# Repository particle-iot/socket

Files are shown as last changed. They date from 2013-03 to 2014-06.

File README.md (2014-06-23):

The Spark Socket
=====

These are the design files for the Spark Socket, developed by Hex Labs, Inc. dba Spark Devices.

These files have been made available online through a [Creative Commons Attribution-ShareAlike 3.0](http://creativecommons.org/licenses/by-sa/3.0/) license.

You are welcome to distribute, remix, and use these files for commercial purposes. If you do so, please attribute the original design to Spark Devices both on the website and on the physical packaging of the product or in the instruction manual. All derivative works must be published under the same or a similar license.

## WARNING: High voltage

If you choose to use these design files, please be forewarned: working with high voltage designs, especially non-isolated ones, can be extremely dangerous. Please proceed with extreme caution. We cannot guarantee the safety of these designs, as they had not yet been put through certification. If you download these files, you are taking upon yourself any liability for injury or property damage.

## The Story

Development of the Spark Socket began in December, 2011, sparked (sorry) by Zach's experiences with his deaf father. Over the next eleven months, Spark went from an idea to a product. On November 13, 2012, the Spark Socket was published on the crowdfunding platform Kickstarter. The Kickstarter campaign site can be found [here](http://www.kickstarter.com/projects/sparkdevices/spark-upgrade-your-lights-with-wi-fi-and-apps).

The Spark Socket Kickstarter campaign ran from November 13, 2012 to December 13, 2012. In that time, roughly 1,600 individuals devoted their time and money to supporting Spark with a total of $125,588 pledged. The funding threshold, however, for the campaign was $250,000. Because that threshold was not reached by the end of the campaign, the campaign closed unsuccessfully, and no credit cards were charged.

The Spark team continued to work on the Spark Socket after the close of the campaign, taking pre-orders on [their website](http://www.sparkdevices.com) . Between December 13, 2012 and March 25, 2013, orders for ~1,800 Spark Sockets were placed; many were from previous Kickstarter backers, and many more were from newcomers.

On March 25, 2013, the Spark team announced that they would be discontinuing development work on the Spark Socket. The design files for the product were released here on github for others to use and learn from.

## What's Included

This distro contains two versions of the Spark Socket, named Version 1 and Version 2.

Version 1 of the Spark Socket is the version that was showcased in our Kickstarter video. The design includes four circuit boards, wrapped in a cuboid shape around the inner core of the plastic enclosure.

As development on the Socket continued, Version 2 of the Spark Socket was created. Version 2 re-oriented the design so that there are only two circuit boards: one with the high voltage components of the circuit, the other with the low voltage components of the circuit. This design made integrating the power supply much easier, and would be significantly easier to assemble. It also had enough empty space that the plastic enclosure could theoretically be made smaller, although development efforts stopped before the outer enclosure was changed.

## Basic structure

The design of the Spark Socket includes four major subsystems:

- **Power supply**. The Socket sources the power for its circuitry directly from the high-voltage AC line to which it is attached. Although this may be possible with an isolated switch-mode power supply, we chose a non-isolated design to save on the bill of materials and to save space. The power supply must be able to source at least 300mA of current (mostly for the transmit events of the Wi-Fi module), although the average power draw should be closer to 50mA.
- **Micro-controller**. Because the Spark Socket was originally built using an Arduino, the micro-controller we are using is an Atmel ATmega328p. This is a low-cost 8-bit micro-controller that is very easy to develop for. For encrypted communications, a 32-bit micro-controller (such as an STM32 Cortex M3) may be used instead.
- **Wi-Fi module**. For the Socket prototype, we used a Roving Networks RN-171 Wi-Fi module. These modules are great because they are very easy to work with and get up and running quickly. They are, however, quite expensive; even with high volumes, the order price was greater than $15. Spark will be using the Texas Instruments CC3000 Wi-Fi module in our other projects, which is smaller, lower cost, and has a simpler set-up process. We recommend the CC3000 for ongoing development work.
- **TRIAC Dimmer**. The most tried-and-true way to dim a light bulb is using a TRIAC. A zero-cross detector informs the micro-controller of the timing of the AC current, and the TRIAC dimmer is activated at a specificied time interval after the zero-cross, based on the chosen dim level. TRIAC dimmers work best with resistive loads (such as incandescent bulbs), and will also work with CFLs that are labeled "dimmable" as well as LED bulbs that are labeled "dimmable". TRIAC dimmers are also called "leading edge" dimmers.

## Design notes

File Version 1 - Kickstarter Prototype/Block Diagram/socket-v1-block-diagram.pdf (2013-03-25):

Potential design changes:
- Use a lower cost Wi-Fi module
- Use a transformerless power supply
- Add a current sensor

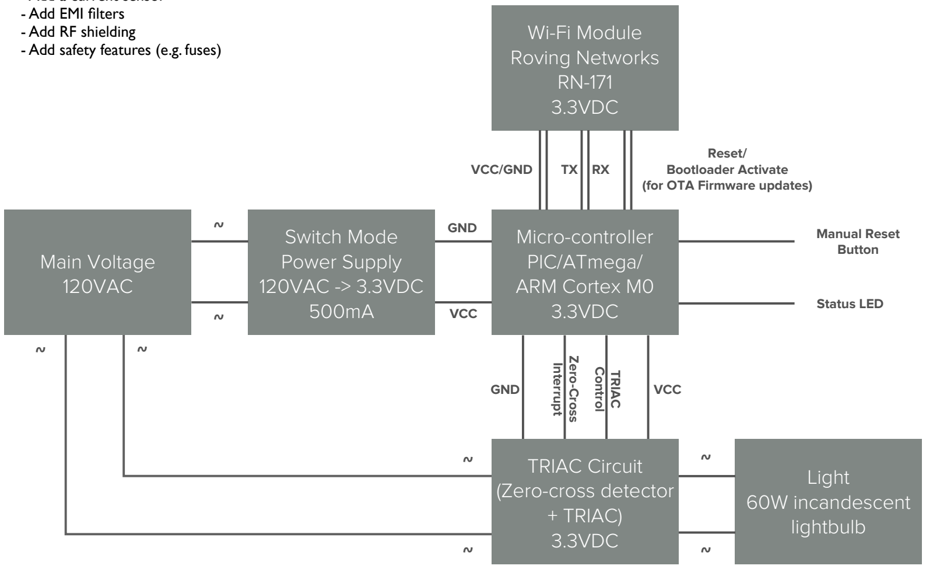
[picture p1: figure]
Switch Mode Power Supply 120VAC -> 3.3VDC 500mA; Micro-controller PIC/ATmega/ ARM Cortex M0 3.3VDC; Wi-Fi Module Roving Networks RN-171 3.3VDC; Light 60W incandescent lightbulb; VCC; GND; Reset/ Bootloader Activate (for OTA Firmware updates); Zero-Cross; Interrupt; Control; TRIAC; VCC/GND; Manual Reset Button; Status LED; Main Voltage 120VAC; TRIAC Circuit (Zero-cross detector + TRIAC) 3.3VDC; - Add EMI filters - Add RF shielding - Add safety features (e.g. fuses)

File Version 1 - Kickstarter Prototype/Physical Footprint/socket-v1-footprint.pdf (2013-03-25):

# Insert

54mm max outer diameter
49mm inner diameter

Shell

PCB

28mm inner diameter
32mm outer diameter
(2mm thick plastic)

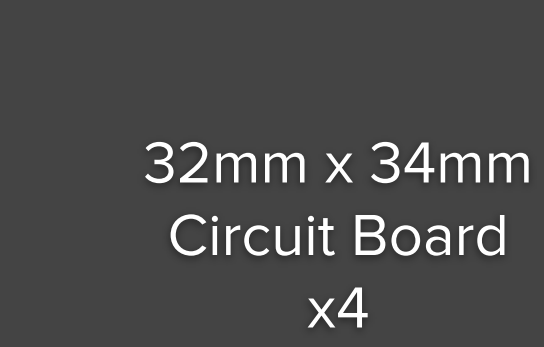
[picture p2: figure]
32mm x 36mm Circuit Board x4; 32mm x 34mm Circuit Board x4

Shell max height: 42mm
PCB height: 34mm
Insert top gradient: 4mm (Z-axis) Shell bottom gradient: 2mm (Z-axis) Plastic thickness: 2mm
34 + 4 + 2 + 2 = 42mm

Thursday, September 27, 12

Female socket
28mm x 22mm

Available space for power supply 28mm x 12mm

Available space for
power supply
19mm x 18mm

PCB

PCB

42mm | 34

23mm
outer diameter

28mm
inner diameter

19mm
inner diameter

49mm
inner diameter

16mm

Thursday, September 27, 12

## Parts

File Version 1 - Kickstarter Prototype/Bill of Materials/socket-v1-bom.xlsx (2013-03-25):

 | SwitchDevices RFQ BOM for <<CM>>
 | 2012-10-08
 | *** Company Confidential *** |  |  |  |  | Material | Density (g/cm3) | Density (lb/in3)
 | Bill@DragonInnovation.com |  |  |  |  | ABS | 1.04 | 0.037
 |  |  |  |  |  | PC | 1.20 | 0.043
CM Instructions: | 1. Please fill in all yellow cells. |  |  |  |  | Nylon | 1.15 | 0.041
 | 2. All costs in USD. |  |  |  |  | Santoprene | 0.97 | 0.035
 | 3. All units in English. |  |  |  |  | Silicone | 1.20 | 0.043
 | 4. Please add any additional costs |  |  |  |  | Styrene | 0.91 | 0.033
 |  |  |  |  |  | POM | 1.41 | 0.051
 |  |  |  |  |  | Aluminum | 2.70 | 0.097
 |  |  |  |  |  | Stainless Steel | 8.03 | 0.289
Molded Parts
Production Tool Cost | Part Name | P/N | Image | Approx Outer Dimensions (L x W X D) | Resin | Color | Resin Cost USD/ Kg | Individual Part Volume (mm3) | Individual Part Weight (g) | Cavities (Usage) | Up | Total Part Weight / Shot (g) | Sprue & Runner Weight (g) | Shot Weight (g) | Regrind % | Virgin Resin Weight / Shot (g) | Material Cost per piece | Press Tonnage | Cycle Time (s) | Press Tonnage Hourly Labor Rate | Mold Type | Molding Cost | Molding Cost / Piece | Production Cost per Piece | Cost per Assy | Total Weekly Capacity
$9738 | Shell | Enclosure2 |  | 55x55x40.5 | PC-ABS V0 Flame Retardant | varies | $4.00 | 18234.3 | 20.42 | 1 | 1 | 20.5763 | 2.05763 | 22.63395 | 0% | 22.63395 | $0.091 |  | 40 | $8.00 |  | $0.089 | $0.089 | $0.179 | $0.179
 | Pairing/Reset Button | Temp003 | No image - small button that is always the same color as the Housing and is molded in a family mold with the Shell | 5x5x7 |  |  |  | 137.4 | 0.15 | 1 | 1
$1640 | Light-pipe | Lightpipe1 | No image - small star-shaped light-pipe that conducts light from LED on PCB to exterior | 4x4x7 | Acrylic or PC V0 Flame Retardant | clear | $5.00 | 88.0 | 0.09 | 1 | 1 | 0.0915 | 0.00915 | 0.10063 | 0% | 0.10063 | $0.001 |  | 20 | $8.00 |  | $0.044 | $0.044 | $0.045 | $0.045
$8649 | Insert | Enclosure1 |  | 49.5x49.5x54 | PC-ABS V0 Flame Retardant | varies | $4.00 | 12218.2 | 13.68 | 1 | 1 | 13.6843 | 1.36843 | 15.05277 | 0% | 15.05277 | $0.060 |  | 40 | $8.00 |  | $0.089 | $0.089 | $0.149 | $0.149
$20027 | Injection Tooling |  |  |  |  |  |  |  |  |  |  |  |  |  |  |  |  |  |  |  |  |  |  | Total Mech | $0.373
Purchased Parts
Usage | Part Name | P/N | Image | Material | Unit Cost | Extended Cost
1 | Screw to attach male Edison screw | Screw3 |  | Stainless steel | $0.080 | $0.080
1 | Screw to attach female Edison screw | Screw4 |  | Stainless steel | $0.080 | $0.080
1 | Male E27 Edison Screw Assembly, see http://www.alibaba.com/product-gs/354788193/GOOD_Lamp_base_E27_Aluminum_Nickel.html | Edison1 |  | Aluminum nickel free solder | $0.080 | $0.080
1 | Female E27 Edison Screw Assembly, see http://www.alibaba.com/product-gs/354775792/GREAT_Lamp_base_E27_Brass_Shrapnel.html | Edison2 |  | Aluminum nickel free solder | $0.220 | $0.220
1 | Wire Hrness between MALE & POWPRI | WH1 |  | Each is a set of four insulated tinned jumper wires | $0.070 | $0.070
1 | Wire Hrness between MALE & DIMMER | WH2 |  | Each is a set of four insulated tinned jumper wires | $0.070 | $0.070
1 | Wire Hrness between FEMALE & DIMMER | WH3 |  | Each is a set of four insulated tinned jumper wires | $0.070 | $0.070
 |  |  |  |  |  | $0.000
 |  |  |  |  |  | $0.000
 |  |  |  |  | Total Purchased | $0.670
 |  |  |  |  |  |  |  |  |  |  |  |  |  |  |  |  |  |  |  | Threshold | $1.00
Item | Description | Usage | Reference | Current Manufacturer | Current Mfg P/N | Possible Alternates | Local Supplier Name | Local Supplier Part Number | Unit Cost | MOQ | Lead-Time (days) | Extended Cost | Unit Cost <= Threshold | Unit Cost > Threshold | Notes
1 | Chip Antenna, 2.4Ghz, SMD 2.2x6.5mm | 1 | A1 | Linx Technologies Inc | ANT-2.45-CHP-T |  |  |  | 0 | ~10K |  | $0.000 | $0.000 |  | Removed
2 | Bridge Rectifier, 400V, DF-S | 1 | B1 | Diodes inc | DF1504S |  |  |  | 0.162 | ~10K |  | $0.162 | $0.162
3 | Bridge rectifier, 0.5A, 600V, SOIC4 | 1 | B2 | Vishay General Semiconductor | MB6S-E3/80 |  |  |  | 0.109 | ~10K |  | $0.109 | $0.109
4 | Button, 5mm height, 6mm | 1 | BUTTON1 | Omron Electronics | B3F-1022 |  |  |  | 0.189 | ~10K |  | $0.189 | $0.189
5 | Capacitor, 1uF, 0603 | 1 | C1 | Std |  |  |  |  | 0.005 | ~10K |  | $0.005 | $0.005
6 | Electrolytic capacitor, 6.8uF, 400V, 8mmx16mm, 5mm leads | 1 | C10 | TEAPO | ?? |  |  |  | 0.141 | ~10K |  | $0.141 | $0.141
7 | Electrolytic capacitor, 470uF, 6.3V, 6.3mmx11mm, 5mm leads | 1 | C11 | Rubycon | 6.3ZLH470M6 |  |  |  | 0.072 | ~10K |  | $0.072 | $0.072
8 | Electrolytic capacitor, 470uF, 6.3V, 6.3mmx11mm, 5mm leads | 1 | C12 | Rubycon | 6.3ZLH470M6 |  |  |  | 0.072 | ~10K |  | $0.072 | $0.072
9 | Ceramic capacitor, 0.1uF, 0603 | 1 | C13 | Std | Std |  |  |  | 0.0045 | ~10K |  | $0.004 | $0.004
10 | Electrolytic capacitor, 10uF, 1206 | 1 | C2 | Std |  |  |  |  | 0.02 | ~10K |  | $0.020 | $0.020
11 | Ceramic capacitor, 0.1uF, 450V, 1206 | 1 | C3 | TDK | C3216X7T2W104M |  |  |  | 0.105 | ~10K |  | $0.105 | $0.105
12 | Capacitor, 0.1uF, 0603 | 1 | C4 | Std |  |  |  |  | 0.0045 | ~10K |  | $0.004 | $0.004
13 | Capacitor, 22pF, 0603 | 1 | C5 | Std |  |  |  |  | 0.09 | ~10K |  | $0.090 | $0.090
14 | Ceramic capacitor, 470pF, 630V, 1206 | 1 | C6 | Kemet | C1206C471KBRACTU |  |  |  | 0.19112 | ~10K |  | $0.191 | $0.191
15 | Ceramic capacitor, 8pF, 10V, 0603 | 1 | C7 | Std | Std |  |  |  | 0.0045 | ~10K |  | $0.004 | $0.004
16 | Ceramic capacitor, 0.33uF, 50V, 0603 | 1 | C8 | Std | Std |  |  |  | 0.0045 | ~10K |  | $0.004 | $0.004
17 | Capacitor, 22pF, 0603 | 1 | C9 | Std |  |  |  |  | 0.0045 | ~10K |  | $0.004 | $0.004
18 | Schotty Diode, 3A, 40V, SMA | 1 | D1 | ON | MBRA340T3G |  |  |  | 0.161 | ~10K |  | $0.161 | $0.161
19 | Switching diode, 0.2A, 200V, SOD323 | 1 | D2 | ON | BAS20HT1G |  |  |  | 0.028 | ~10K |  | $0.028 | $0.028
20 | Ultrafast rectifier, 1A, 600V, SMA | 1 | D3 | ON | MURA160T3G |  |  |  | 0.10687 | ~10K |  | $0.107 | $0.107
21 | Fuse, 300V, TE5 | 1 | F1 | Littelfuse Inc | 36911000000 |  |  |  | 0.18 | ~10K |  | $0.180 | $0.180
22 | PTC, 1A, 1206 | 1 | F2 | Littelfuse Inc | 1206L050YR |  |  |  | 0.178 | ~10K |  | $0.178 | $0.178
23 | Header b/w MCU & WIFI, 6 pin, right angle, 0.1 inch spacing | 1 | HEADER1 | TE Connectivity | 640385-6 |  |  |  | 0.33 | ~10K |  | $0.330 | $0.330
24 | Header b/w MCU & DIMMER, 4 pin, right angle, 0.1 inch spacing | 1 | HEADER2 | TE Connectivity | 640385-4 |  |  |  | 0.11 | ~10K |  | $0.110 | $0.110
25 | Header b/w WIFI & POWREG, 3 pin, right angle, 0.1 inch spacing | 1 | HEADER3 | Wurth | 640385-3 |  |  |  | 0.2 | ~10K |  | $0.200 | $0.200
26 | ICSP Headers, 2x3 (6 pins), 0.1 inch spacing | 3 | ICSP2 | Std |  |  |  |  | 0.11 | ~10K |  | $0.330 | $0.330
27 | Radial leaded wire transformer, 2.2mH, 5mmx8mm leaded | 1 | L1 | Wurth Electronik | 7447462222 |  |  |  | 0.175 | ~10K |  | $0.175 | $0.175
28 | LED, Green, 0603 | 1 | LED3 | Std |  |  |  |  | 0.07 | ~10K |  | $0.070 | $0.070
29 | LED, Yellow, 0603 | 1 | LED4 | Std |  |  |  |  | 0.07 | ~10K |  | $0.070 | $0.070
30 | LED, Red, 0603 | 1 | LED5 | Std |  |  |  |  | 0.07 | ~10K |  | $0.070 | $0.070
31 | LED, Red, 0603 | 1 | LED6 | Std |  |  |  |  | 0.07 | ~10K |  | $0.070 | $0.070
32 | Triple Output LED RGB; common anode, , 4-PLCC | 1 | LED7 | Cree Inc | CLVBA-FKA-CAEDH8BBB7A363 |  |  |  | 0.126 | ~10K |  | $0.126 | $0.126 |  | Replaced with http://www.digikey.com/product-detail/en/LTST-C19FD1WT/LTST-C19FD1WT-ND/3198709
33 | Printed Circuit Board, 26mmx28mm, Std, | 1 | PCB1 | Std |  |  |  |  | 0.080 | ~10K |  | $0.080 | $0.080
34 | Printed Circuit Board, 35mmx28mm, Std, | 1 | PCB2 | Std |  |  |  |  | 0.110 | ~10K |  | $0.110 | $0.110
35 | Printed Circuit Board, 35mmx28mm, | 1 | PCB3 | Std |  |  |  |  | 0.110 | ~10K |  | $0.110 | $0.110
36 | Printed Circuit Board, 26mmx28mm, Std, | 1 | PCB4 | Std |  |  |  |  | 0.080 | ~10K |  | $0.080 | $0.080
37 | Printed Circuit Board inside male shell 19 mm Diam. | 1 | PCB5 | Std |  |  |  |  | 0.050 | ~10K |  | $0.050 | $0.050
38 | Printed Circuit Board inside male shell 28 mm Diam. | 1 | PCB6 | Std |  |  |  |  | 0.100 | ~10K |  | $0.100 | $0.100
39 | Crystal, 12Mhz, HC49/US SMD | 1 | Q1 | ECS Inc | ECS-120-20-3X-TR |  |  |  | 0.189 | ~10K |  | $0.189 | $0.189
40 | NMOSFET, 2A, 600V, TO-220 | 1 | Q2 | Fairchild Semiconductor | FQP2N60C |  |  |  | 0.3 | ~10K |  | $0.300 | $0.300
41 | Resistor, 10K, 0603 | 1 | R1 | Std |  |  |  |  | 0.002 | ~10K |  | $0.002 | $0.002
42 | Resistor, 200 ohm, 0603 | 1 | R10 | Std |  |  |  |  | 0.002 | ~10K |  | $0.002 | $0.002
43 | Resistor, 200 ohm, 0603 | 1 | R11 | Std |  |  |  |  | 0.002 | ~10K |  | $0.002 | $0.002
44 | Resistor, 220 ohm, 0603 | 1 | R12 | Std |  |  |  |  | 0.002 | ~10K |  | $0.002 | $0.002
45 | Resistor, 220 ohm, 0603 | 1 | R13 | Std |  |  |  |  | 0.002 | ~10K |  | $0.002 | $0.002
46 | Resistor, 220 ohm, 0603 | 1 | R14 | Std |  |  |  |  | 0.002 | ~10K |  | $0.002 | $0.002
47 | Resistor, 10K, 0603 | 1 | R15 | Std |  |  |  |  | 0.002 | ~10K |  | $0.002 | $0.002
48 | Resistor, 4.7K, 0805 | 1 | R16 | Std | Std |  |  |  | 0.002 | ~10K |  | $0.002 | $0.002
49 | Resistor, 10K, 0603 | 1 | R17 | Std |  |  |  |  | 0.002 | ~10K |  | $0.002 | $0.002
50 | Resistor, 330K, 1206 | 1 | R18 | Std | Std |  |  |  | 0.002 | ~10K |  | $0.002 | $0.002
51 | Resistor, 0ohm, 1206 | 1 | R19 | Std | Std |  |  |  | 0.002 | ~10K |  | $0.002 | $0.002
52 | Resistor, 47K, 0603 | 1 | R2 | Std |  |  |  |  | 0.002 | ~10K |  | $0.002 | $0.002
53 | Resistor, 7.5M, 1206 | 1 | R20 | Std | Std |  |  |  | 0.002 | ~10K |  | $0.002 | $0.002
54 | Resistor, 7.5M, 1206 | 1 | R21 | Std | Std |  |  |  | 0.002 | ~10K |  | $0.002 | $0.002
55 | Resistor, 33R, 0603 | 1 | R22 | Std | Std |  |  |  | 0.002 | ~10K |  | $0.002 | $0.002
56 | Resistor, 150K, 0603 | 1 | R23 | Std | Std |  |  |  | 0.002 | ~10K |  | $0.002 | $0.002
57 | Resistor, 28K, 0603 | 1 | R24 | Std | Std |  |  |  | 0.002 | ~10K |  | $0.002 | $0.002
58 | Resistor, 47K, 0603 | 1 | R26 | Std | Std |  |  |  | 0.002 | ~10K |  | $0.002 | $0.002
59 | Resistor, 2.4K, 0603 | 1 | R27 | Std | Std |  |  |  | 0.002 | ~10K |  | $0.002 | $0.002
60 | Resistor, 2.4ohm, 0603 | 1 | R28 | Std | Std |  |  |  | 0.002 | ~10K |  | $0.002 | $0.002
61 | Resistor, 18ohm, 0805 | 1 | R29 | Std | Std |  |  |  | 0.002 | ~10K |  | $0.002 | $0.002
62 | Resistor, 47K, 0603 | 1 | R3 | Std |  |  |  |  | 0.002 | ~10K |  | $0.002 | $0.002
63 | Resistor, 4.7K, 0603 | 1 | R30 | Std | Std |  |  |  | 0.002 | ~10K |  | $0.002 | $0.002
64 | Resistor, 330ohm, 0603 | 1 | R4 | Std |  |  |  |  | 0.002 | ~10K |  | $0.002 | $0.002
65 | Resistor, 470ohm, 0603 | 1 | R5 | Std |  |  |  |  | 0.002 | ~10K |  | $0.002 | $0.002
66 | Resistor, 1K, 0603 | 1 | R6 | Std |  |  |  |  | 0.002 | ~10K |  | $0.002 | $0.002
67 | Resistor, 1K, 0603 | 1 | R7 | Std |  |  |  |  | 0.002 | ~10K |  | $0.002 | $0.002
68 | Resistor, 1M, 0603 | 1 | R8 | Std |  |  |  |  | 0.002 | ~10K |  | $0.002 | $0.002
69 | Resistor, 100 ohm, 0603 | 1 | R9 | Std |  |  |  |  | 0.002 | ~10K |  | $0.002 | $0.002
70 | Screw to attach MCU to INSERT, , | 1 | SCREW1 | Std |  |  |  |  | 0.03 | ~10K |  | $0.030 | $0.030
71 | Screw to attach POWREG to INSERT, , Std | 1 | SCREW2 | Std |  |  |  |  | 0.03 | ~10K |  | $0.030 | $0.030
72 | Screw to attach POWREG to INSERT, , | 1 | SCREW3 | Std |  |  |  |  | 0.03 | ~10K |  | $0.030 | $0.030
73 | TRIAC, 600V, SOT-223 | 1 | T1 | NXP Semiconductors | ACT108W-600E,135 |  |  |  | 0.17 | ~10K |  | $0.170 | $0.170
74 | Transformer, EPC13, Custom | 1 | TR1 | Wurth Electronik | 750341445 |  |  |  | 0 | ~10K |  | $0.000 | $0.000 |  | Removed
75 | Optoisolator transistor, , 6-SMD | 1 | U1 | Fairchild Optoelectronics Group | 4N25SR2M |  |  |  | 0.163 | ~10K |  | $0.163 | $0.163
76 | Optoisolator TRIAC driver, 400V, 6-SMD | 1 | U2 | Lite-On Inc | MOC3021S |  |  |  | 0.21735 | ~10K |  | $0.217 | $0.217
77 | 3.3V voltage regulator, 3.3V, SOT-235 | 1 | U3 | Micrel Inc | MIC5219-3.3YM5 TR |  |  |  | 0 | ~10K |  | $0.000 | $0.000 |  | Removed
78 | ATmega328p Micro-controller, ATmega328p, 32TQFP | 1 | U4 | Atmega | ATMEGA328P-AU |  |  |  | 1.76 | ~10K |  | $1.760 |  | $1.760
79 | Roving Networks RN-171 Wi-Fi Module, 802.11b/g, Custom SMD | 1 | U5 | Roving Networks | 740-1042-ND |  |  |  | 12.5 | ~10K |  | $12.500 |  | $12.500 | Replaced with GainSpan 1011MIPS
80 | PSR Controller, UCC28700, TSOP-6 | 1 | U6 | Texas Instruments | UCC28700 |  |  |  | 0.49 | ~10K |  | $0.490 | $0.490
 |  |  |  |  |  |  |  |  |  |  | Total | $19.851 | $5.591 | $14.260
Production Labor Cost Per Unit | $5.50
Shipment Packaging
Usage | Description | Unit Cost | Setup / Tooling Cost | Extended Cost
0.0833 | Master Carton | $0.350 |  | $0.029
1 | Gift Box, 4x4" | $0.850 |  | $0.850 | Replace with printed corrugated shipper; no price difference
1 | Foam packaging (FOAM) | $0.250 | $80 | $0.250 | Reduced to $0.25 (cheaper packaging)
1 | Slip Cover, 4-Color | $0.000 |  | $0.000 | Removed
1 | Warranty Card | $0.050 |  | $0.050
1 | Instructions, 1 page on B&W stock | $0.250 |  | $0.250
2 | Tape | $0.020 |  | $0.040
 |  |  | Shipment Packaging Total | $1.469
 |  |  | Giftbox Packaging (Injection) | $0.000
 |  |  | Total Packaging | $1.469
 |  |  | Packout Labor Cost / Unit | $0.400
 | COGS Summary | Value
 | Special Component Threshold | $1.00
 | Labor Rate per Hour
 | Standard Factory Profit (%) | 15.00%
 | Special Materials Factory Profit (%) | 8.00%
 | Consigned Goods Markup (%)
 | Total Mechanical Costs (including Packaging) | $2.51
 | Total Standard Electrical Costs | $5.59
 | Total Special Electrical Costs | $14.26
 | Total Consigned Costs | $0.00
 | Total Material Costs | $22.36
 | Total Labor Cost (including Packaging) | $5.90
 | Total Markup | $3.24
 | Total XF Cost | $31.50
 | Overland Transportation - 20ft | Value
 | HK FCL
 | HK LCL
 | YanTian FCL
 | YanTian LCL
 | Total Costs | Value
 | FOB, HK FCL | $31.50
 | FOB, HK LCL | $31.50
 | FOB, YanTian FCL | $31.50
 | FOB, YanTian LCL | $31.50
 | Total Tooling Costs | $20107

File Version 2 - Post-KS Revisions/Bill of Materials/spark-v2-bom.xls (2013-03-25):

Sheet: Components
System | Part | Description | Value | Package | Manufacturer | Mgfr Part # | DigiKey Part # | Link | Cost @ 1 unit | Cost @ 10K units | Notes | Quantity
MCU | U4 | ATmega328p Micro-controller | ATmega328p | 32TQFP | Atmega | ATMEGA328P-AU | ATMEGA328P-AU-ND | http://www.digikey.com/product-detail/en/ATMEGA328P-AU/ATMEGA328P-AU-ND/1832260 | $3.0500 | $1.7600 | Will probably switch to QFN for production design | 1
MCU | R8 | Resistor | 1M | 0603 | Panasonic Electronics Components | ERJ-3GEYJ105V | P1.0MGCT-ND | http://www.digikey.com/product-detail/en/ERJ-3GEYJ105V/P1.0MGCT-ND/134885 |  |  |  | 1
MCU | R15 | Resistor | 10K | 0603 | Panasonic Electronics Components | ERJ-3GEYJ103V | P10KGCT-ND | http://www.digikey.com/product-detail/en/ERJ-3GEYJ103V/P10KGCT-ND/134717 |  |  |  | 1
MCU | Q1 | Crystal | 8Mhz | HC49/US SMD | ECS Inc | ECS-80-18-5PX-TR | XC1271CT-ND | http://www.digikey.com/product-detail/en/ECS-80-18-5PX-TR/XC1271CT-ND/827735 | $0.5300 | $0.1890 | Bump to 12Mhz? | 1
MCU | C5 | Capacitor | 22pF | 0603 | TDK Corporation | C1608C0G1H220J | 445-1273-1-ND | http://www.digikey.com/product-detail/en/C1608C0G1H220J/445-1273-1-ND/567670 |  |  | Must match the crystal | 1
MCU | C9 | Capacitor | 22pF | 0603 | TDK Corporation | C1608C0G1H220J | 445-1273-1-ND | http://www.digikey.com/product-detail/en/C1608C0G1H220J/445-1273-1-ND/567670 |  |  | Must match the crystal | 1
MCU | LED7 | Triple Output LED RGB; common anode |  | 4-PLCC | Cree Inc | CLVBA-FKA-CAEDH8BBB7A363 | CLVBA-FKA-CAEDH8BBB7A363CT-ND | http://www.digikey.com/product-detail/en/CLVBA-FKA-CAEDH8BBB7A363/CLVBA-FKA-CAEDH8BBB7A363CT-ND/2650500 | $0.5500 | $0.2730 |  | 1
MCU | R9 | Resistor | 100 ohm | 0603 | Panasonic Electronics Components | ERJ-3GEYJ101V | P100GCT-ND | http://www.digikey.com/product-detail/en/ERJ-3GEYJ101V/P100GCT-ND/134714 |  |  |  | 1
MCU | R10 | Resistor | 200 ohm | 0603 | Panasonic Electronics Components | ERJ-3GEYJ201V | P200GCT-ND | http://www.digikey.com/product-detail/en/ERJ-3GEYJ201V/P200GCT-ND/134748 |  |  |  | 1
MCU | R11 | Resistor | 200 ohm | 0603 | Panasonic Electronics Components | ERJ-3GEYJ201V | P200GCT-ND | http://www.digikey.com/product-detail/en/ERJ-3GEYJ201V/P200GCT-ND/134748 |  |  |  | 1
WIFI | U5 | Roving Networks RN-171 Wi-Fi Module | 802.11b/g | Custom SMD | Roving Networks | 740-1042-ND | 740-1042-ND | http://www.digikey.com/product-search/en/rf-if-and-rfid/rf-transceivers/3539948?k=rn-171 | $33.3300 | $15.0000 | 10K price quoted from Roving Networks. We expect to replace this with a lower cost module. Alternatives can be found on the "Potential Wi-Fi Modules" worksheet | 1
WIFI | LED3 | LED | Green | 0603 | Vishay Semiconductors | LTST-C190KGKT | 160-1435-1-ND | http://www.digikey.com/product-detail/en/LTST-C190KGKT/160-1435-1-ND/386814 |  |  |  | 1
WIFI | LED4 | LED | Yellow | 0603 | Vishay Semiconductors | LTST-C190KFKT | 160-1434-1-ND | http://www.digikey.com/product-detail/en/LTST-C190KFKT/160-1434-1-ND/386812 |  |  |  | 1
WIFI | LED5 | LED | Red | 0603 | Lite-On Inc | LTST-C190KRKT | 160-1436-1-ND | http://www.digikey.com/product-detail/en/LTST-C190KRKT/160-1436-1-ND/386816 |  |  |  | 1
WIFI | R12 | Resistor | 220 ohm | 0603 | Std | ERJ-3GEYJ221V | P220GCT-ND | http://www.digikey.com/product-detail/en/ERJ-3GEYJ221V/P220GCT-ND/134754 |  |  |  | 1
WIFI | R13 | Resistor | 220 ohm | 0603 | Std | ERJ-3GEYJ221V | P220GCT-ND | http://www.digikey.com/product-detail/en/ERJ-3GEYJ221V/P220GCT-ND/134754 |  |  |  | 1
WIFI | R14 | Resistor | 220 ohm | 0603 | Std | ERJ-3GEYJ221V | P220GCT-ND | http://www.digikey.com/product-detail/en/ERJ-3GEYJ221V/P220GCT-ND/134754 |  |  |  | 1
WIFI | A1 | Chip Antenna | 2.4Ghz | SMD 2.2x6.5mm | Linx Technologies Inc | ANT-2.45-CHP-T | ANT-2.45-CHPCT-ND | http://www.digikey.com/product-detail/en/ANT-2.45-CHP-T/ANT-2.45-CHPCT-ND/523153 | $1.4200 | $1.1250 | Expect to replace with etched antenna or find a WiFi module with integrated antenna | 1
DIMMER | U1 | Optoisolator transistor |  | 6-SMD | Fairchild Optoelectronics Group | 4N25SR2M | 4N25SR2MCT-ND | http://www.digikey.com/product-detail/en/4N25SR2M/4N25SR2MCT-ND/2094169 | $0.6800 | $0.1630 |  | 1
DIMMER | U2 | Optoisolator TRIAC driver | 400V | 6-SMD | Lite-On Inc | MOC3021S | 160-1375-5-ND | http://www.digikey.com/product-detail/en/MOC3021S/160-1375-5-ND/385845 | $0.6500 | $0.2173 |  | 1
DIMMER | B1 | Bridge Rectifier | 400V | DF-S | Diodes inc | DF1504S | DF1504SDICT-ND | http://www.digikey.com/product-detail/en/DF1504S-T/DF1504SDICT-ND/350404 | $0.5900 | $0.1620 |  | 1
DIMMER | R1 | Resistor | 10K | 0603 | Panasonic Electronics Components | ERJ-3GEYJ103V | P10KGCT-ND | http://www.digikey.com/product-detail/en/ERJ-3GEYJ103V/P10KGCT-ND/134717 |  |  |  | 1
DIMMER | R2 | Resistor | 47K | 1206 | Vishay Dale | CRCW120647K0JNEAHP | 541-47KUACT-ND | http://www.digikey.com/product-detail/en/CRCW120647K0JNEAHP/541-47KUACT-ND/2222999 |  |  |  | 1
DIMMER | R3 | Resistor | 47K | 1206 | Vishay Dale | CRCW120647K0JNEAHP | 541-47KUACT-ND | http://www.digikey.com/product-detail/en/CRCW120647K0JNEAHP/541-47KUACT-ND/2222999 |  |  |  | 1
DIMMER | R4 | Resistor | 330ohm | 0603 | Panasonic Electronics Components | ERJ-3GEYJ331V | P330GCT-ND | http://www.digikey.com/product-detail/en/ERJ-3GEYJ331V/P330GCT-ND/134778 |  |  |  | 1
DIMMER | R5 | Resistor | 470ohm | 0603 | Panasonic Electronics Components | ERJ-3GEYJ471V | P470GCT-ND | http://www.digikey.com/product-detail/en/ERJ-3GEYJ471V/P470GCT-ND/134802 |  |  |  | 1
DIMMER | R6 | Resistor | 1K | 1206 | Vishay Dale | CRCW12061K00JNEAHP | 541-1.0KUACT-ND | http://www.digikey.com/product-detail/en/CRCW12061K00JNEAHP/541-1.0KUACT-ND/2222989 |  |  |  | 1
DIMMER | T1 | TRIAC | 600V | SOT-223 | NXP Semiconductors | ACT108W-600E,135 | 568-4912-1-ND | http://www.digikey.com/product-detail/en/ACT108W-600E,135/568-4912-1-ND/2122742 | $0.6200 | $0.1700 | Will need a heftier TRIAC for production | 1
DIMMER | LED1 | LED | Green | 0603 | Vishay Semiconductors | LTST-C190KGKT | 160-1435-1-ND | http://www.digikey.com/product-detail/en/LTST-C190KGKT/160-1435-1-ND/386814 |  |  |  | 1
POWREG | C13 | Capacitor | 0.1uF | 0603 | TDK Corporation | C1608X7R1E104K | 445-1316-1-ND | http://www.digikey.com/product-detail/en/C1608X7R1E104K/445-1316-1-ND/567697 |  |  |  | 1
POWREG | D1 | Schotty Diode | 3A, 40V | SMA | ON | MBRA340T3G | MBRA340T3GOSCT-ND | http://www.digikey.com/product-detail/en/MBRA340T3G/MBRA340T3GOSCT-ND/917975 | $0.5800 | $0.1610 |  | 1
POWREG | R30 | Resistor | 4.7K | 0603 | Panasonic Electronics Components | ERJ-3GEYJ472V | P4.7KGCT-ND | http://www.digikey.com/product-detail/en/ERJ-3GEYJ472V/P4.7KGCT-ND/135199 |  |  |  | 1
POWREG | C11 | Capacitor | 47uF | 1206 | TDK Corporation | C3216X6S0J476M | 445-6011-1-ND | http://www.digikey.com/product-detail/en/C3216X6S0J476M/445-6011-1-ND/2444052 |  |  |  | 1
POWREG | C12 | Capacitor | 47uF | 1206 | TDK Corporation | C3216X6S0J476M | 445-6011-1-ND | http://www.digikey.com/product-detail/en/C3216X6S0J476M/445-6011-1-ND/2444052 |  |  |  | 1
POWREG | F2 | PTC | 1A | 1206 | Littelfuse Inc | 1206L050YR | F2112CT-ND | http://www.digikey.com/product-detail/en/1206L050YR/F2112CT-ND/455721 | $0.4800 | $0.1780 |  | 1
POWREG | U3 | 3.3V voltage regulator | 3.3V | SOT-235 | Micrel Inc | MIC5219-3.3YM5 TR | 576-1281-1-ND | http://www.digikey.com/product-detail/en/MIC5219-3.3YM5%20TR/576-1281-1-ND/771902 | $1.4300 | $0.6980 |  | 1
POWREG | C2 | Capacitor | 10uF | 1206 | TDK Corporation | C3216X7R1H104M | 445-4008-1-ND | http://www.digikey.com/product-detail/en/C3216X7R1H104M/445-4008-1-ND/1965654 |  |  |  | 1
POWREG | C1 | Capacitor | 1uF | 0603 | TDK Corporation | C1608X7R1E105K | 445-5956-1-ND | http://www.digikey.com/product-detail/en/C1608X7R1E105K/445-5956-1-ND/2443997 |  |  |  | 1
POWREG | C4 | Capacitor | 0.1uF | 0603 | TDK Corporation | C1608X7R1E104K | 445-1316-1-ND | http://www.digikey.com/product-detail/en/C1608X7R1E104K/445-1316-1-ND/567697 |  |  |  | 1
POWREG | R7 | Resistor | 1K | 0603 | Panasonic Electronics Components | ERJ-3GEYJ102V | P1.0KGCT-ND | http://www.digikey.com/product-detail/en/ERJ-3GEYJ102V/P1.0KGCT-ND/134874 |  |  |  | 1
POWREG | LED6 | LED | Red | 0603 | Lite-On Inc | LTST-C190KRKT | 160-1436-1-ND | http://www.digikey.com/product-detail/en/LTST-C190KRKT/160-1436-1-ND/386816 |  |  |  | 1
POWREG | R17 | Resistor | 10K | 0603 | Panasonic Electronics Components | ERJ-3GEYJ103V | P10KGCT-ND | http://www.digikey.com/product-detail/en/ERJ-3GEYJ103V/P10KGCT-ND/134717 |  |  |  | 1
POWREG | BUTTON1 | Button | 5mm height | 6mm | Omron Electronics | B3F-1022 | SW403-ND | http://www.digikey.com/product-detail/en/B3F-1022/SW403-ND/44674 | $0.3500 | $0.1890 | May want to switch to surface mount | 1

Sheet: Specs
Attached bulb
 | Works with any dimmable light (incandescent, CFL, LED)
 | Up to 100W bulb when pointed upward
 | Up to 60W bulb when pointed downward (e.g. recessed lighting)
Quality
 | No visible parting lines
 | No visible blemishes
 | No visible solder or weld marks on either Edison screw
Power
 | Functions in any common AC voltage (85V to 265V)
 | Functions in either 60Hz or 50Hz
Resin
 | High melting point (to manage the heat from the bulb)
 | High light stability in indoor light (to prevent discoloration from the attached bulb)
 | V0 or V1 flame retardancy
 | Must pass glow-wire test and ball pressure test (for CE regulations)
Environmental
 | Product is intended only for indoor use; however, we would still like to reduce safety hazards related to outdoor use
RFI and EMI
 | Device must meet standard RFI and EMI requirements
 | Device must have a Wi-Fi range of 100-300 feet in a standard home; additional RF shielding may be necessary to limit noise from the TRIAC and power supply to achieve this performance
Compliance
 | FCC compliant
 | UL complaint with CCN OLRX (Standard - UL 406 Lamp Holders), CCN XACN3 (Standard - UL 60730-1 Automatic Electrical Controls for Household and Similar Use), and UL 1470: Solid State Dimming Controls.
 | Must meet any other safety and certification requirements to be sold in the US and Europe
Wi-Fi
 | Must be able to connect to a secured (WPA, WPA2, WEP) Wi-Fi 802.11 network
 | Must achieve at least 802.11b performance; may also achieve 802.11g and 802.11n
 | Must be able to create an ad hoc network
 | Must be able to communicate over standard TCP (IPv4 and IPv6)

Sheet: Potential Wi-Fi modules
Manufacturer | Model | Link | Price @ 1 unit | Price @ 10K | Price @ volume | Notes
Roving Networks | RN-171 | http://www.rovingnetworks.com/products/RN_171_RN171_I_RM | $33.00
Murata | SN8200 | http://www.murata-ws.com/sn8200.htm
GainSpan | GS1011MIPS | http://www.gainspan.com/gs1011mips | $33.00 | $12.50 | $10.50 | $12.5 at 10K, $10.5 at 25K
Inventek | ISM4319-M3-L44-E | http://www.inventeksys.com/products-page/wifi-modules/serial-wifi/ism4319-embedded-serial-to-wifi-module/
Inventek | ISM43362-M3G-L44-U (http://components.arrow.com/part/detail/53785148S181507N2846) | http://components.arrow.com/part/detail/53785148S181507N2846
??? | RAK410 | Found by Fred Zhang |  | $10 | $8
Bluegiga | WF121 | http://www.bluegiga.com/wf121-wi-fi-module
Redpine Signals | RS9110-N-11-22-(xx) | http://www.redpinesignals.com/Products/Modules/Connect-io-n/Wireless_Device_Server/RS9110-N-11-22.html
LS Research | TiWi-SL | http://www.lsr.com/wireless-products/tiwi-sl
Laird Technologies | WLM100 | http://www.mouser.com/ProductDetail/Laird-Technologies/WLM100/
WizNet | WizFi210 | http://www.wiznettechnology.com/Sub_Modules/en/product/Product_Detail.asp?cate1=&cate2=&cate3=&pid=1132

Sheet: Assembly steps
1) Mold the two plastic components
2) Laser-etch unique ID number and necessary labels (e.g. UL certification, voltage allowances, etc.) on the bottom of the shell
3) Solder components to 5 PCBs.
4) Load software onto MCU using the 6-pin ICSP headers
5) Weld wires/wire harnesses to the inside of the male Edison screw and the bottom of the female Edison screw
6) Bolt the male Edison screw to the bottom of the Insert
7) Solder the first set of wires from the male Edison screw to the primary-side power supply
8) Snap the primary-side power supply PCB into the inside of the insert
9) Attach 4 PCBs in square shape using soldered 90-degree headers
10) Screw 4 PCB square structure to Insert
11) Bolt the female Edison screw to the inside of the Insert
12) Solder the second set of wires from the male Edison screw to the dimmer circuit
13) Solder the wires from the female Edison screw to the dimmer circuit
14) Electrically connect 4 PCBs to primary-side power supply with wire harnesses
15) Test circuit
16) Snap Light pipe into Shell
17)Snap Shell/Light Pipe assembly onto PCB/Insert assembly
18)Test status light and reset button to ensure proper alignment
19)Visual inspection
20)Packaging

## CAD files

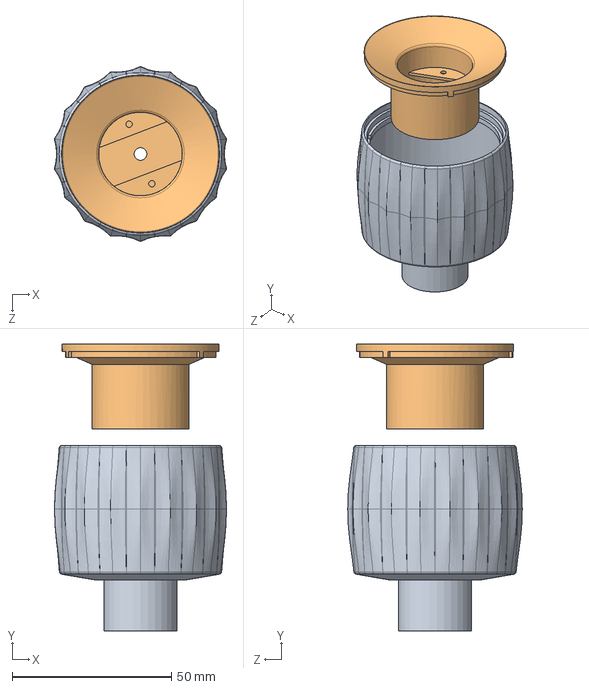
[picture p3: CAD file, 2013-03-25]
Version 2 - Post-KS Revisions/Plastic Shell/socket-v2-assembly.SLDASM
54.0 x 90.2 x 54.9 mm
Pinch_091812-Outer
Pinch_091812-Inner

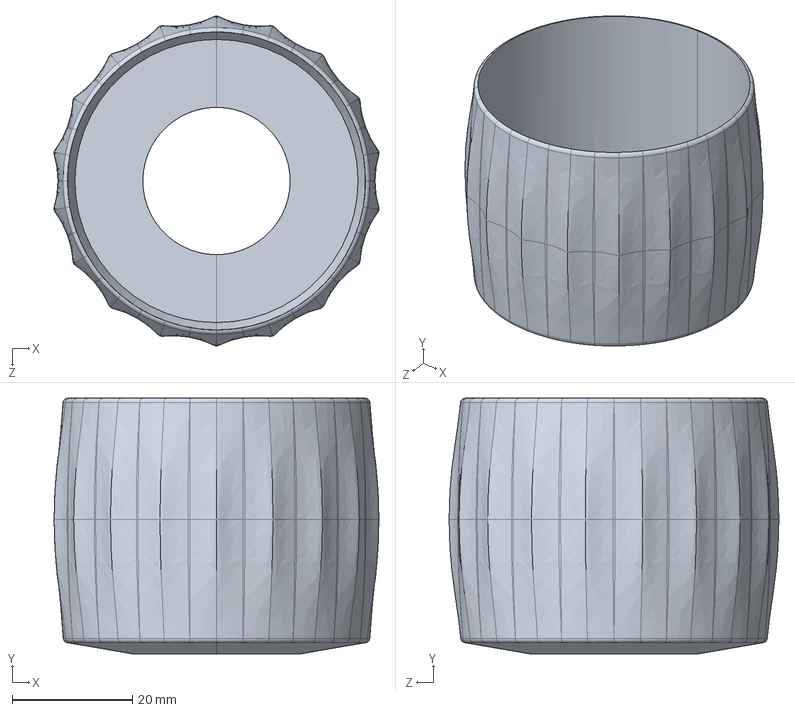
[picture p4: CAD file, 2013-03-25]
Version 1 - Kickstarter Prototype/Plastic Shell/socket-v1-outer-shell.STEP
54.0 x 42.5 x 54.9 mm

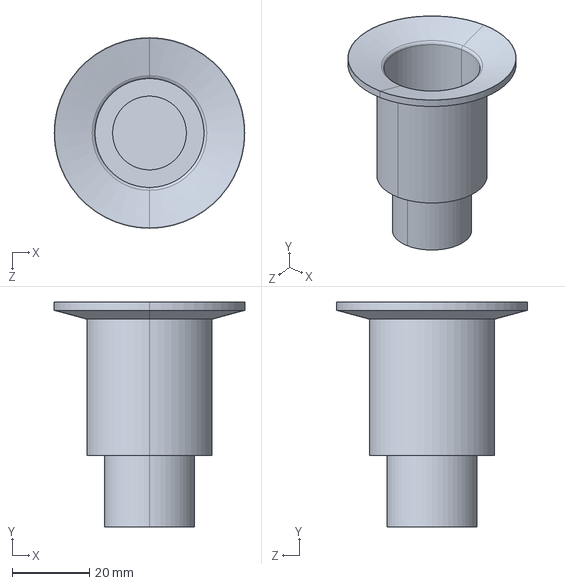
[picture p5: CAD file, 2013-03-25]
Version 1 - Kickstarter Prototype/Plastic Shell/socket-v1-inner-shell.STEP
49.3 x 58.3 x 49.3 mm

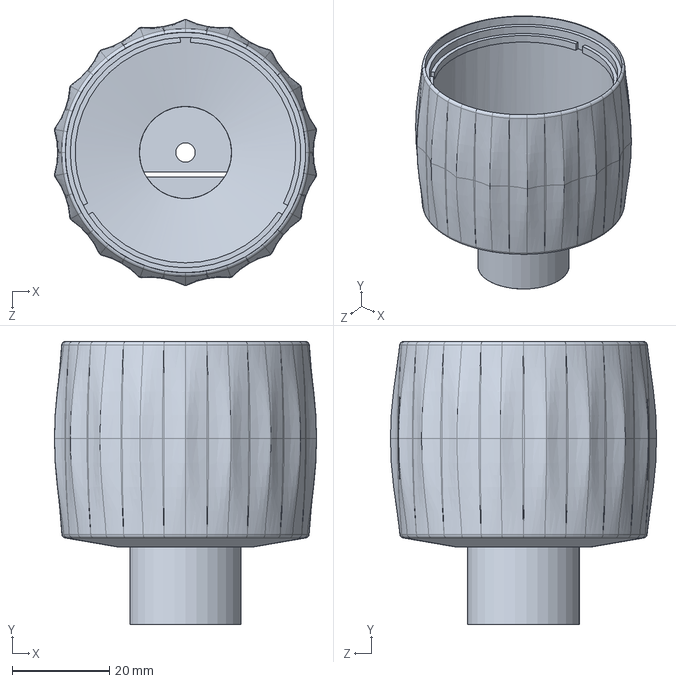
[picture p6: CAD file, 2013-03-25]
Version 2 - Post-KS Revisions/Plastic Shell/socket-v2-lower-shell.SLDPRT
54.0 x 58.3 x 54.9 mm

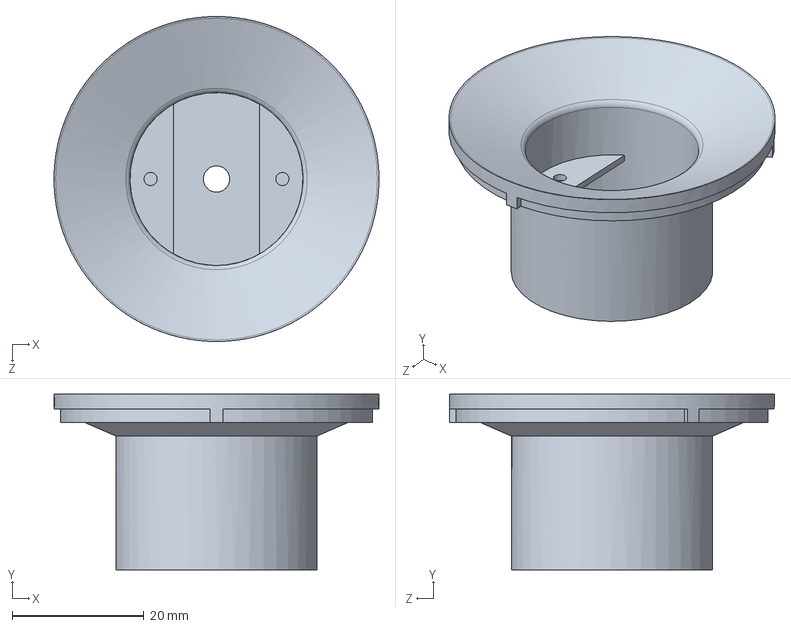
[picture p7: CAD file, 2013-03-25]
Version 2 - Post-KS Revisions/Plastic Shell/socket-v2-upper-shell.SLDPRT
49.3 x 26.7 x 49.3 mm

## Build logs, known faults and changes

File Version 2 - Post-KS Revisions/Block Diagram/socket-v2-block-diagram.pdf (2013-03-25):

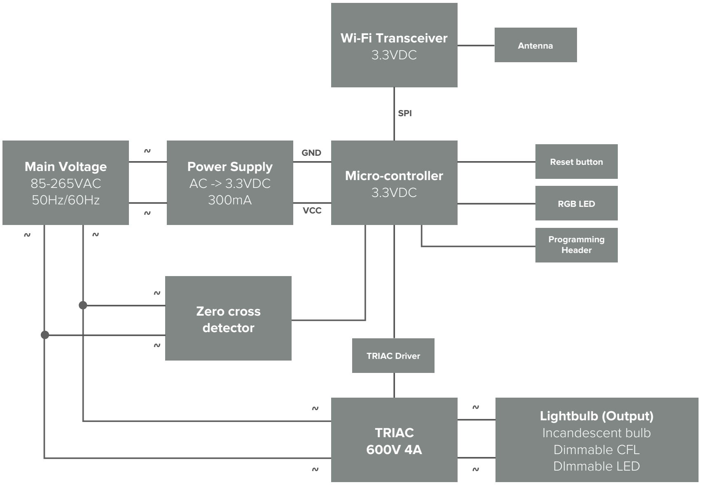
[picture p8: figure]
Power Supply AC -> 3.3VDC 300mA; Micro-controller 3.3VDC; Wi-Fi Transceiver 3.3VDC; Lightbulb (Output) Incandescent bulb Dimmable CFL DImmable LED; VCC; GND; SPI; Main Voltage 85-265VAC 50Hz/60Hz; TRIAC 600V 4A; Zero cross detector; Reset button; RGB LED; Antenna; Programming Header; TRIAC Driver

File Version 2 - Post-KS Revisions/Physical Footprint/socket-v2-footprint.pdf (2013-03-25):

Female socket
28mm x 20mm
Low Voltage PCB

42mm
34mm

23mm
outer diameter

28mm
inner diameter

19mm
inner diameter

49mm
inner diameter

16mm

High Voltage PCB

# Side View

X-axis

Z-axis

54mm max outer diameter
49mm inner diameter

Shell

# Female Edison Screw

Low Voltage PCB

High voltage
PCB

# Top View

X-axis

Y-axis

49mm
inner diameter

Wi-Fi
MCU | Transceiver

RGB

Button

Antenna

# High Voltage

# Low Voltage

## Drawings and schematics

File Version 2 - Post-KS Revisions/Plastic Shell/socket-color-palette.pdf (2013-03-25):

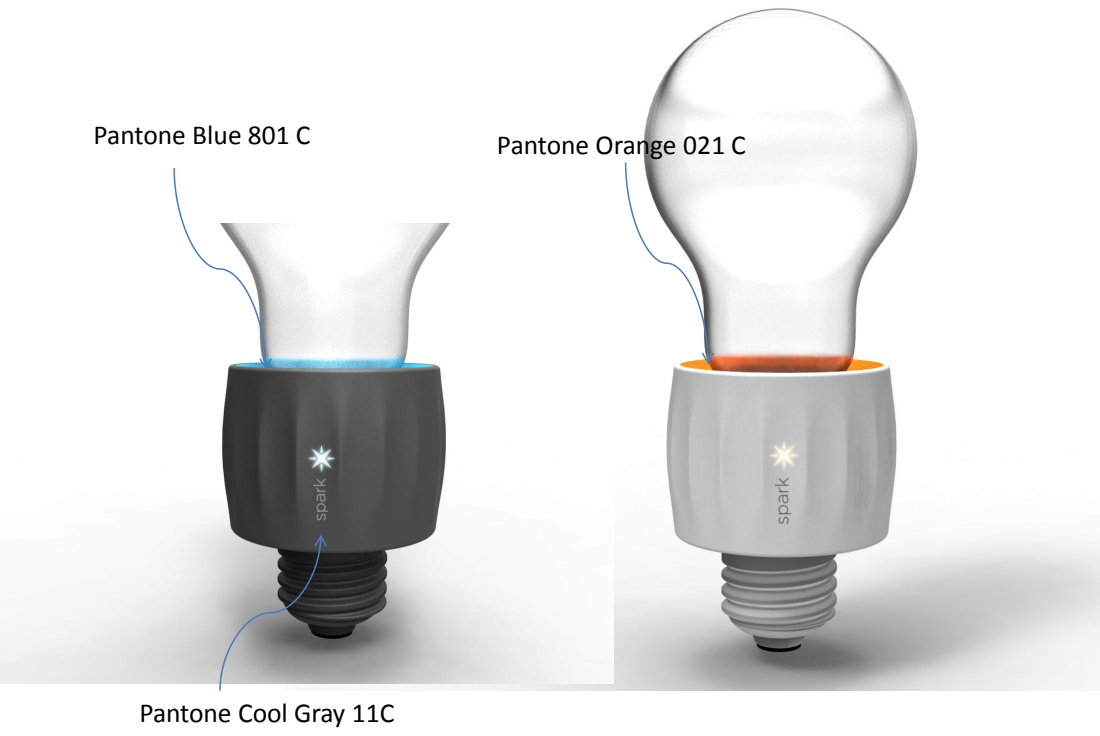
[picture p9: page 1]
Pantone Blue 801 C; Pantone Orange 021 C

Pantone Cool Gray 11C

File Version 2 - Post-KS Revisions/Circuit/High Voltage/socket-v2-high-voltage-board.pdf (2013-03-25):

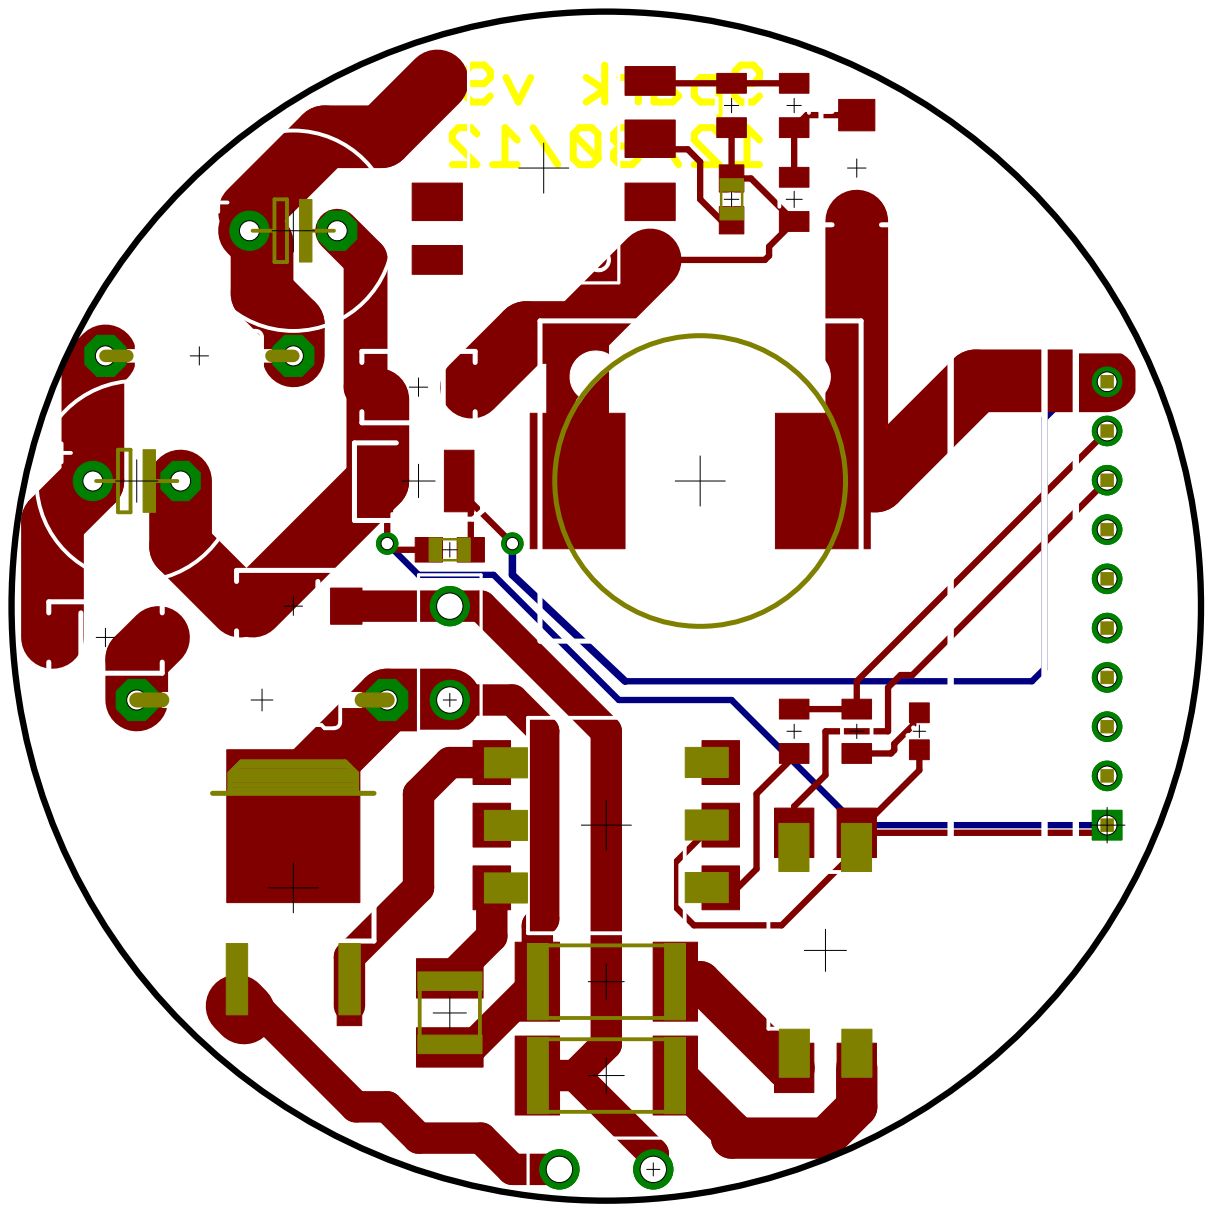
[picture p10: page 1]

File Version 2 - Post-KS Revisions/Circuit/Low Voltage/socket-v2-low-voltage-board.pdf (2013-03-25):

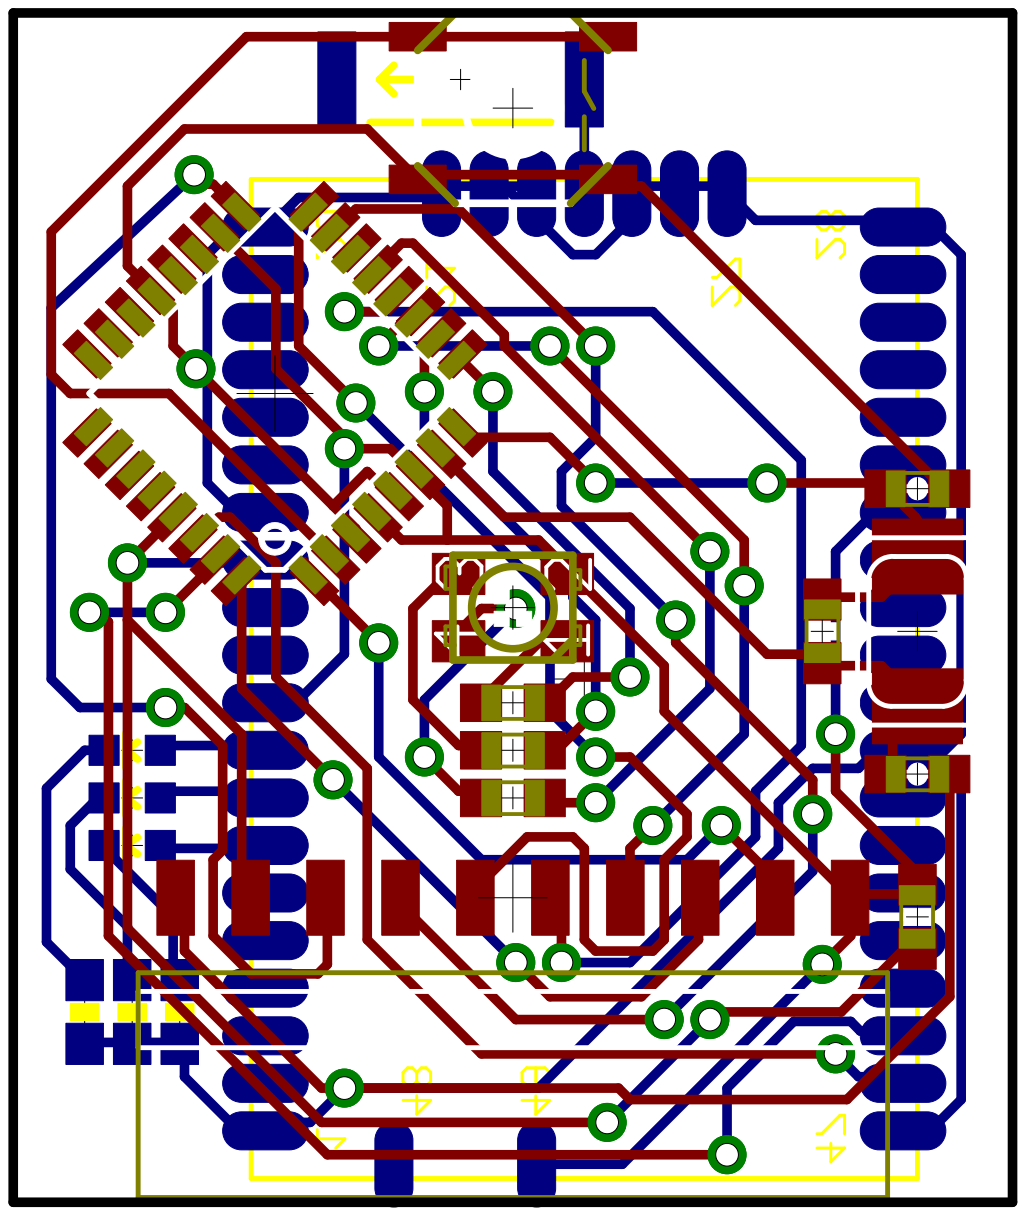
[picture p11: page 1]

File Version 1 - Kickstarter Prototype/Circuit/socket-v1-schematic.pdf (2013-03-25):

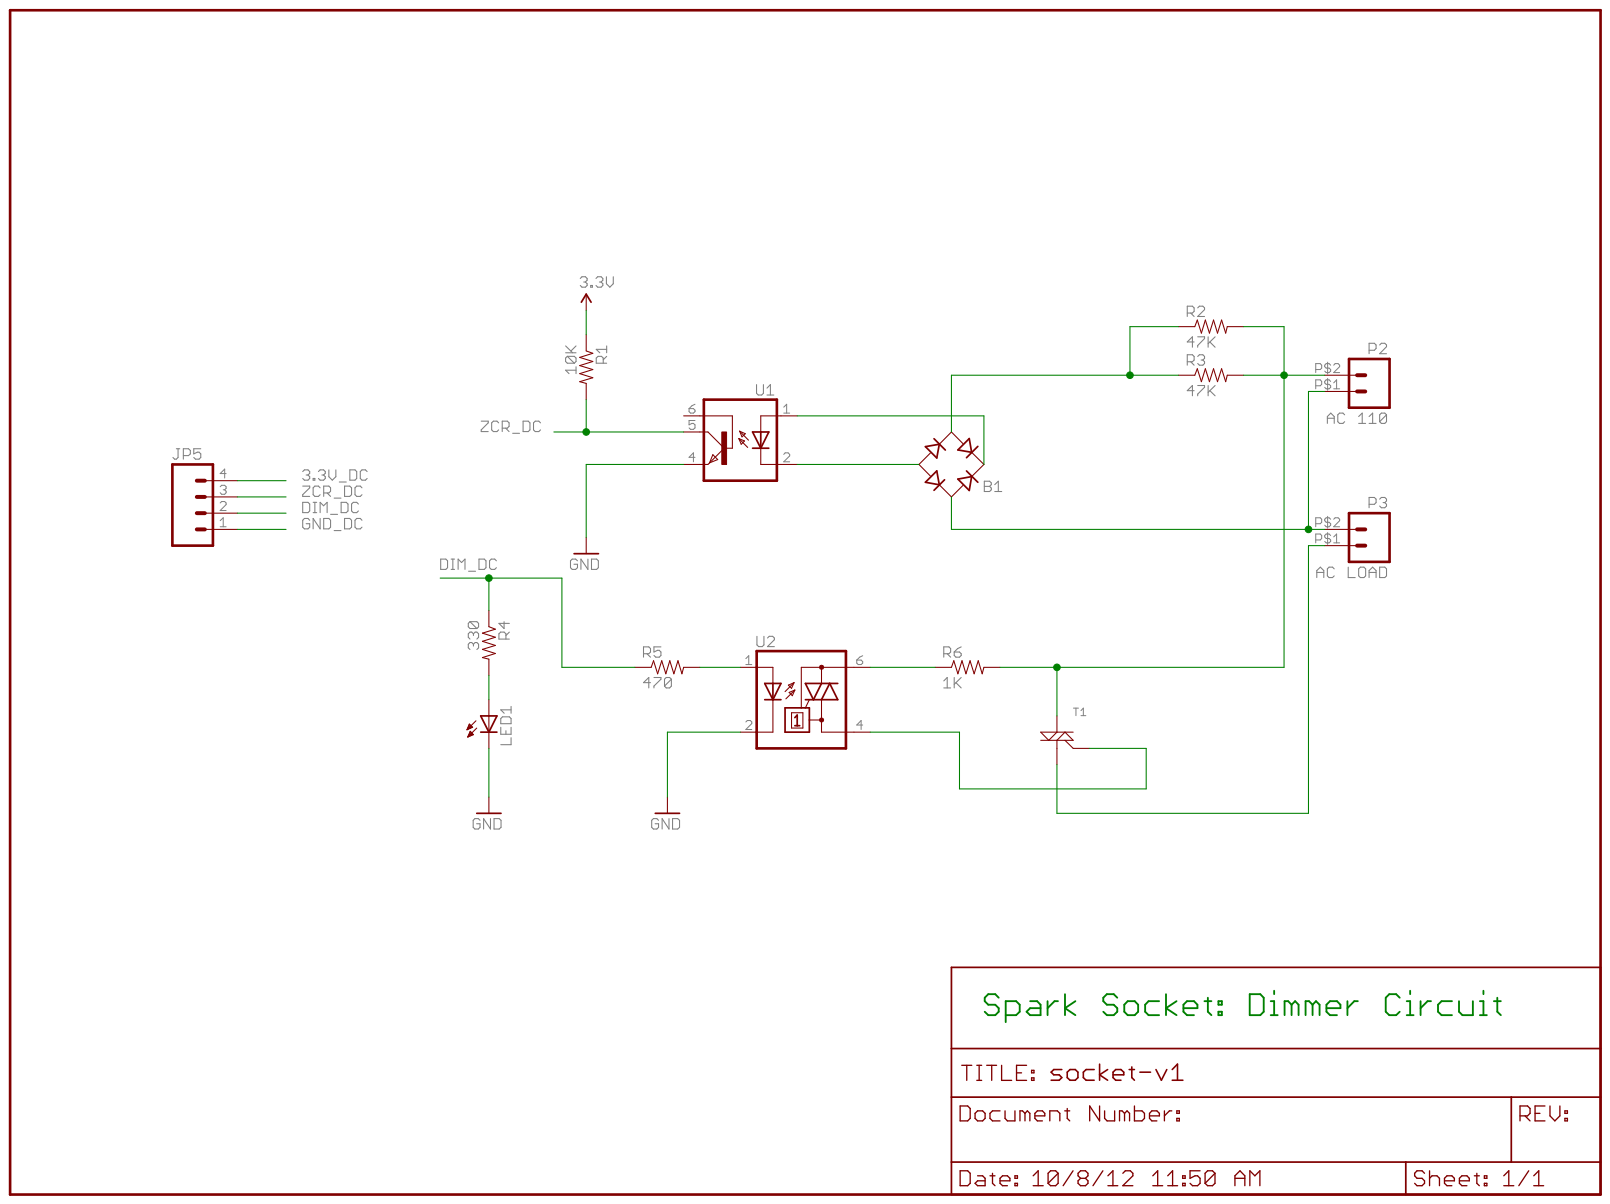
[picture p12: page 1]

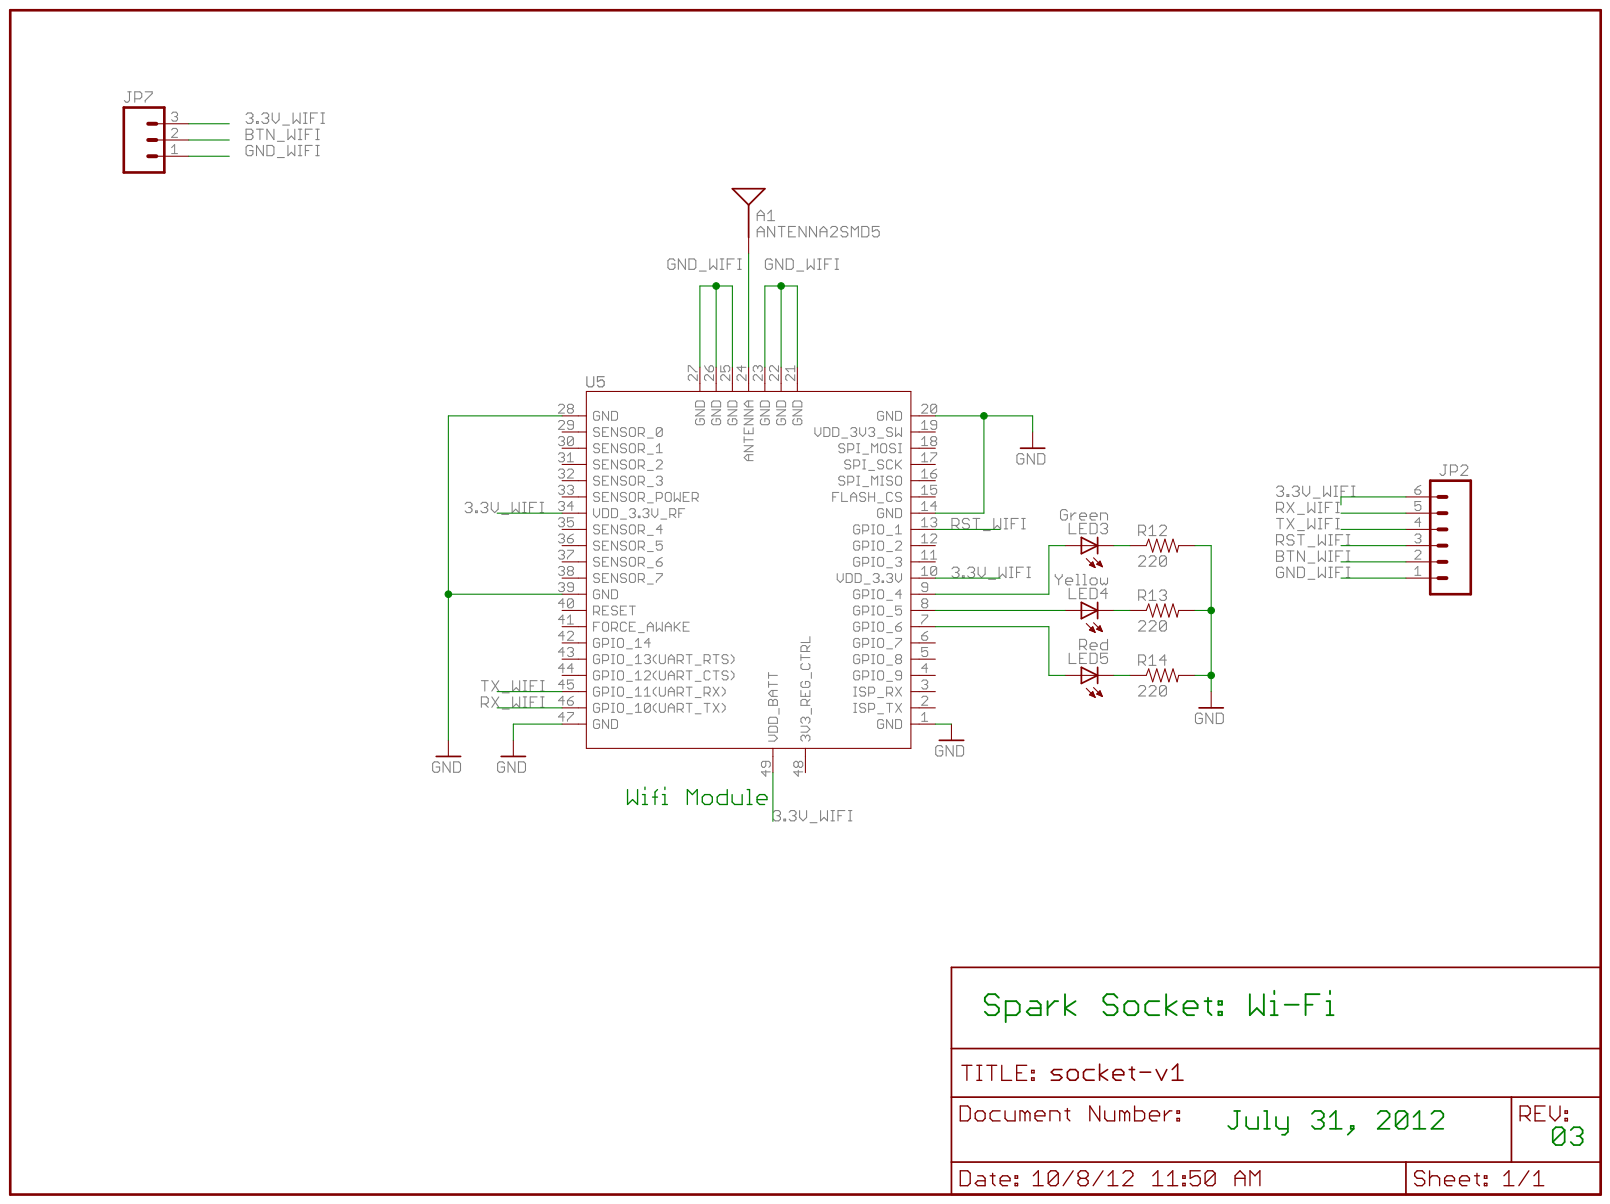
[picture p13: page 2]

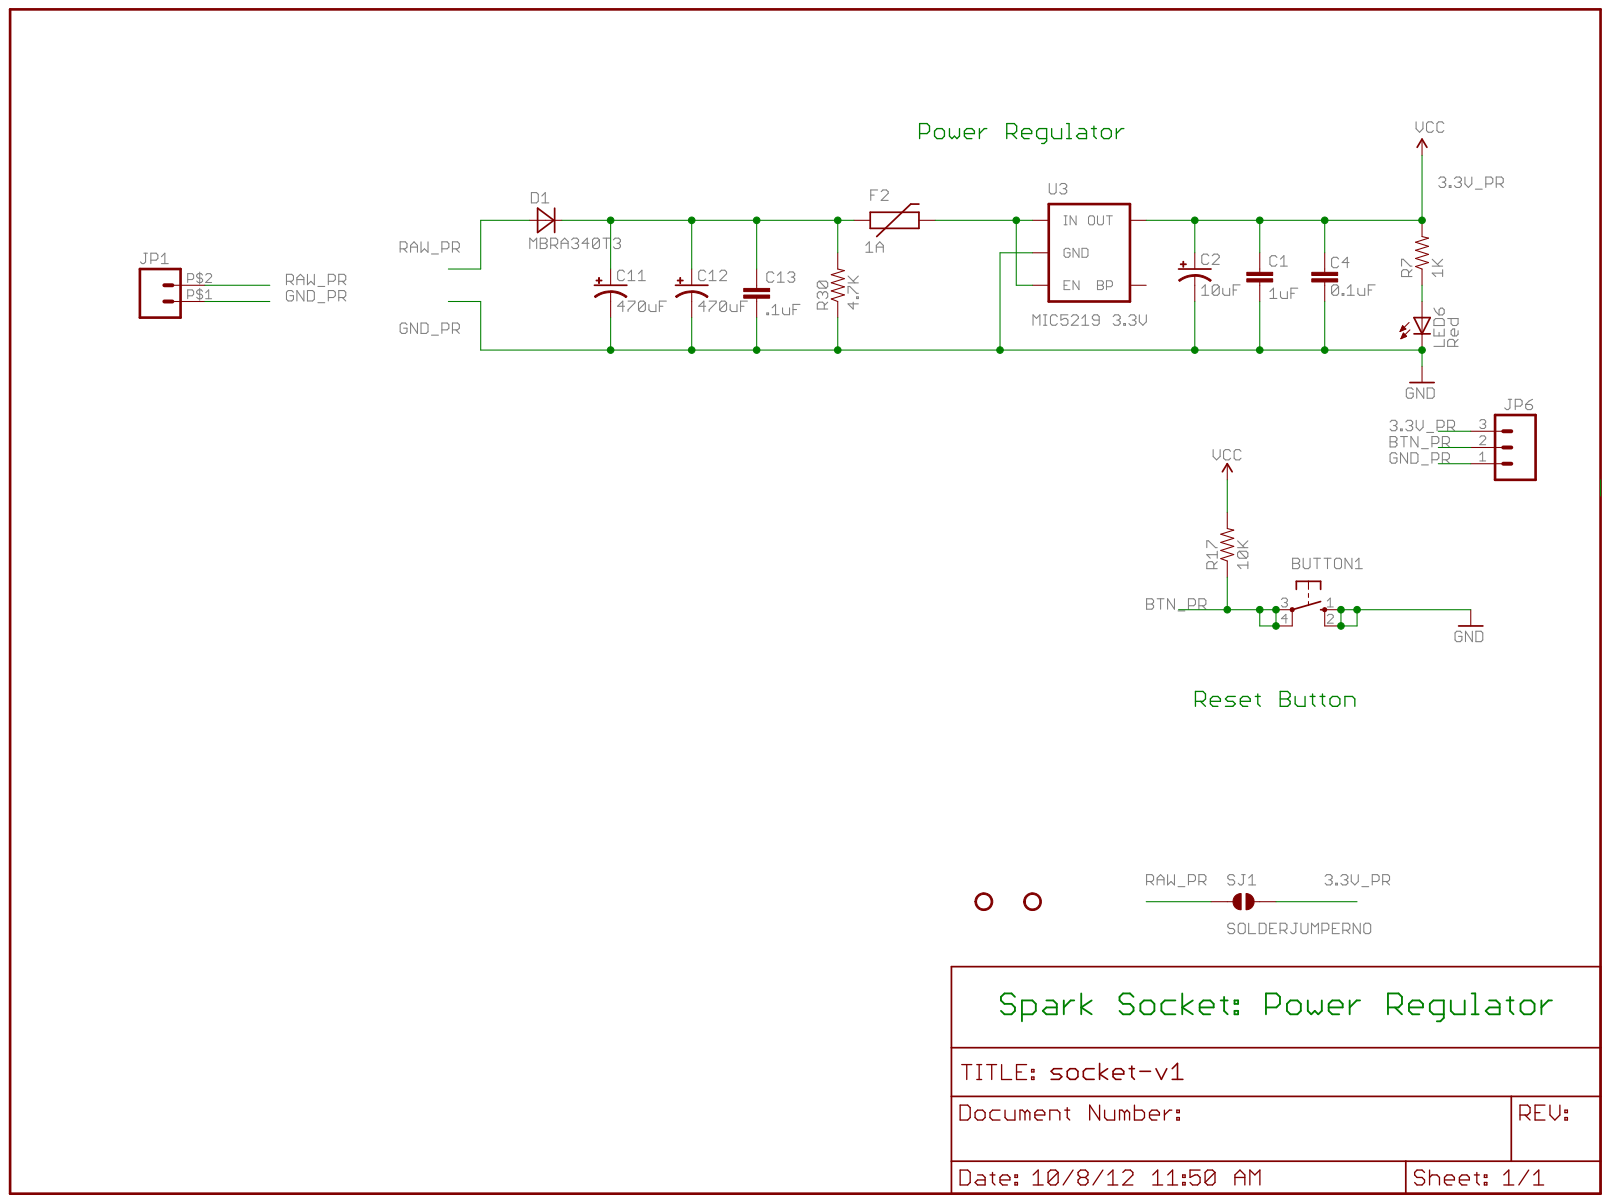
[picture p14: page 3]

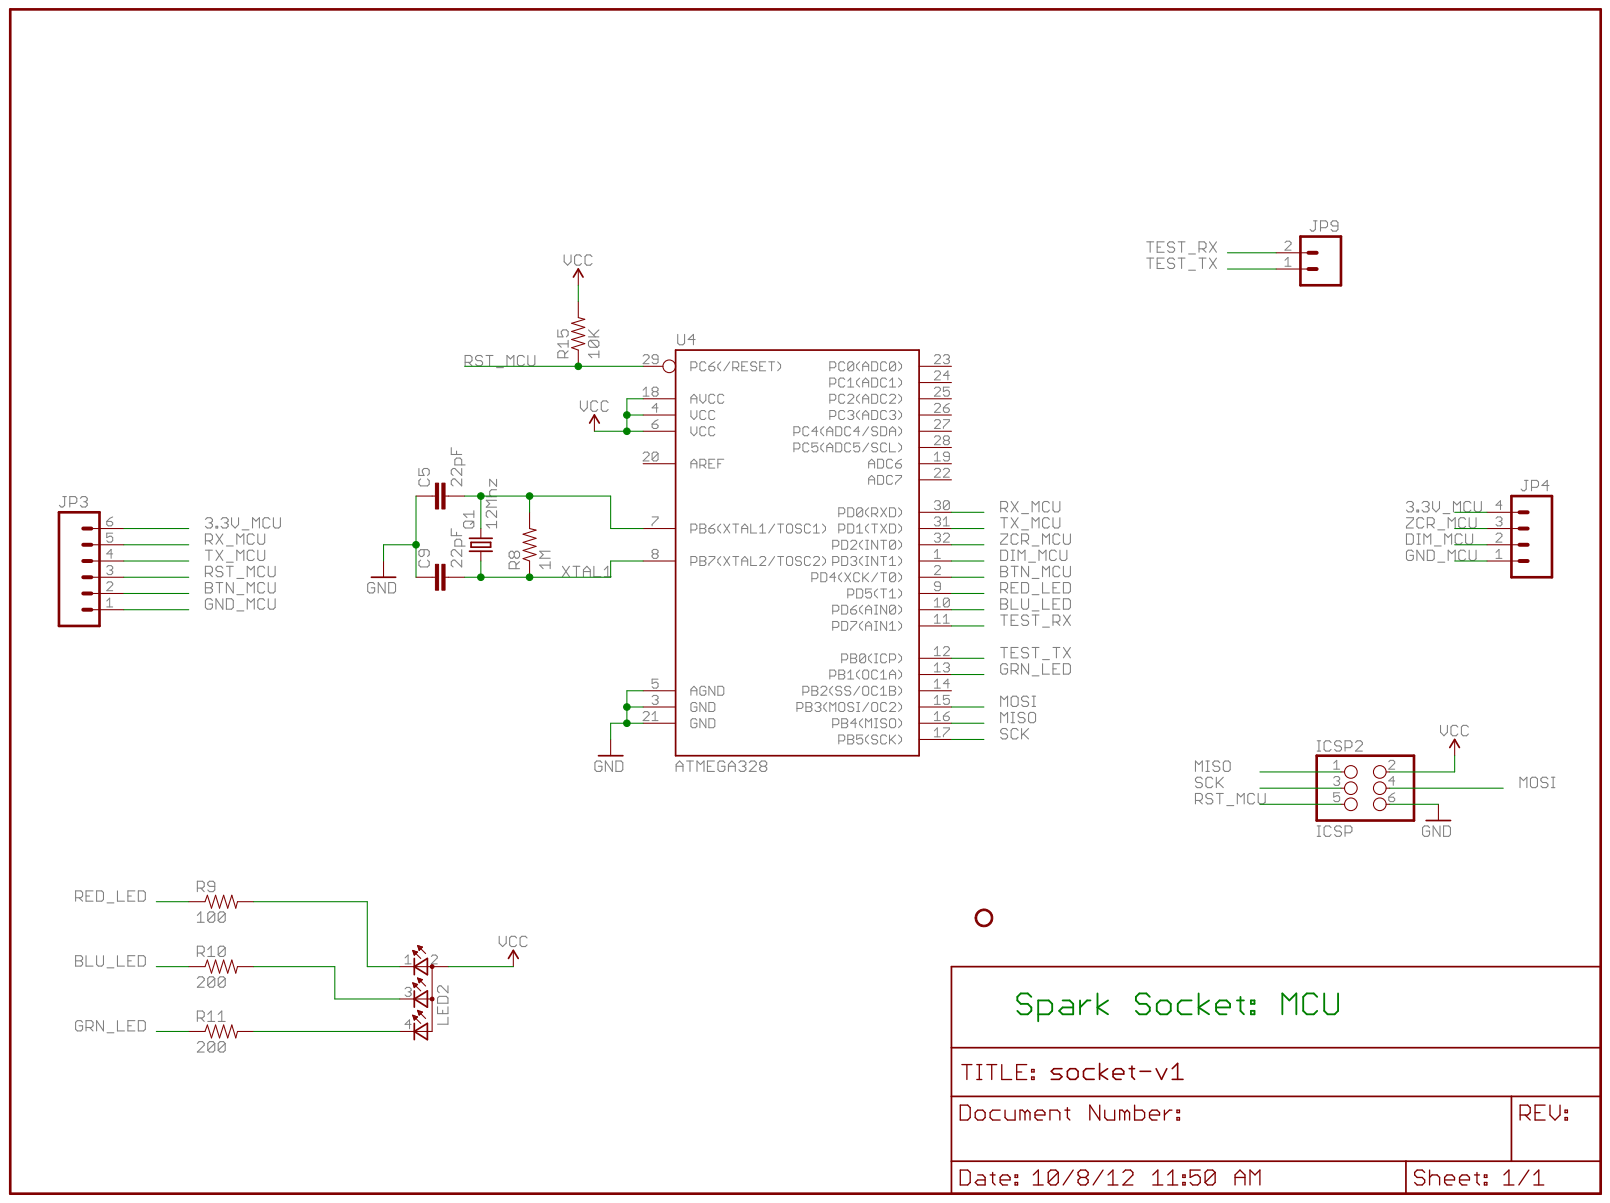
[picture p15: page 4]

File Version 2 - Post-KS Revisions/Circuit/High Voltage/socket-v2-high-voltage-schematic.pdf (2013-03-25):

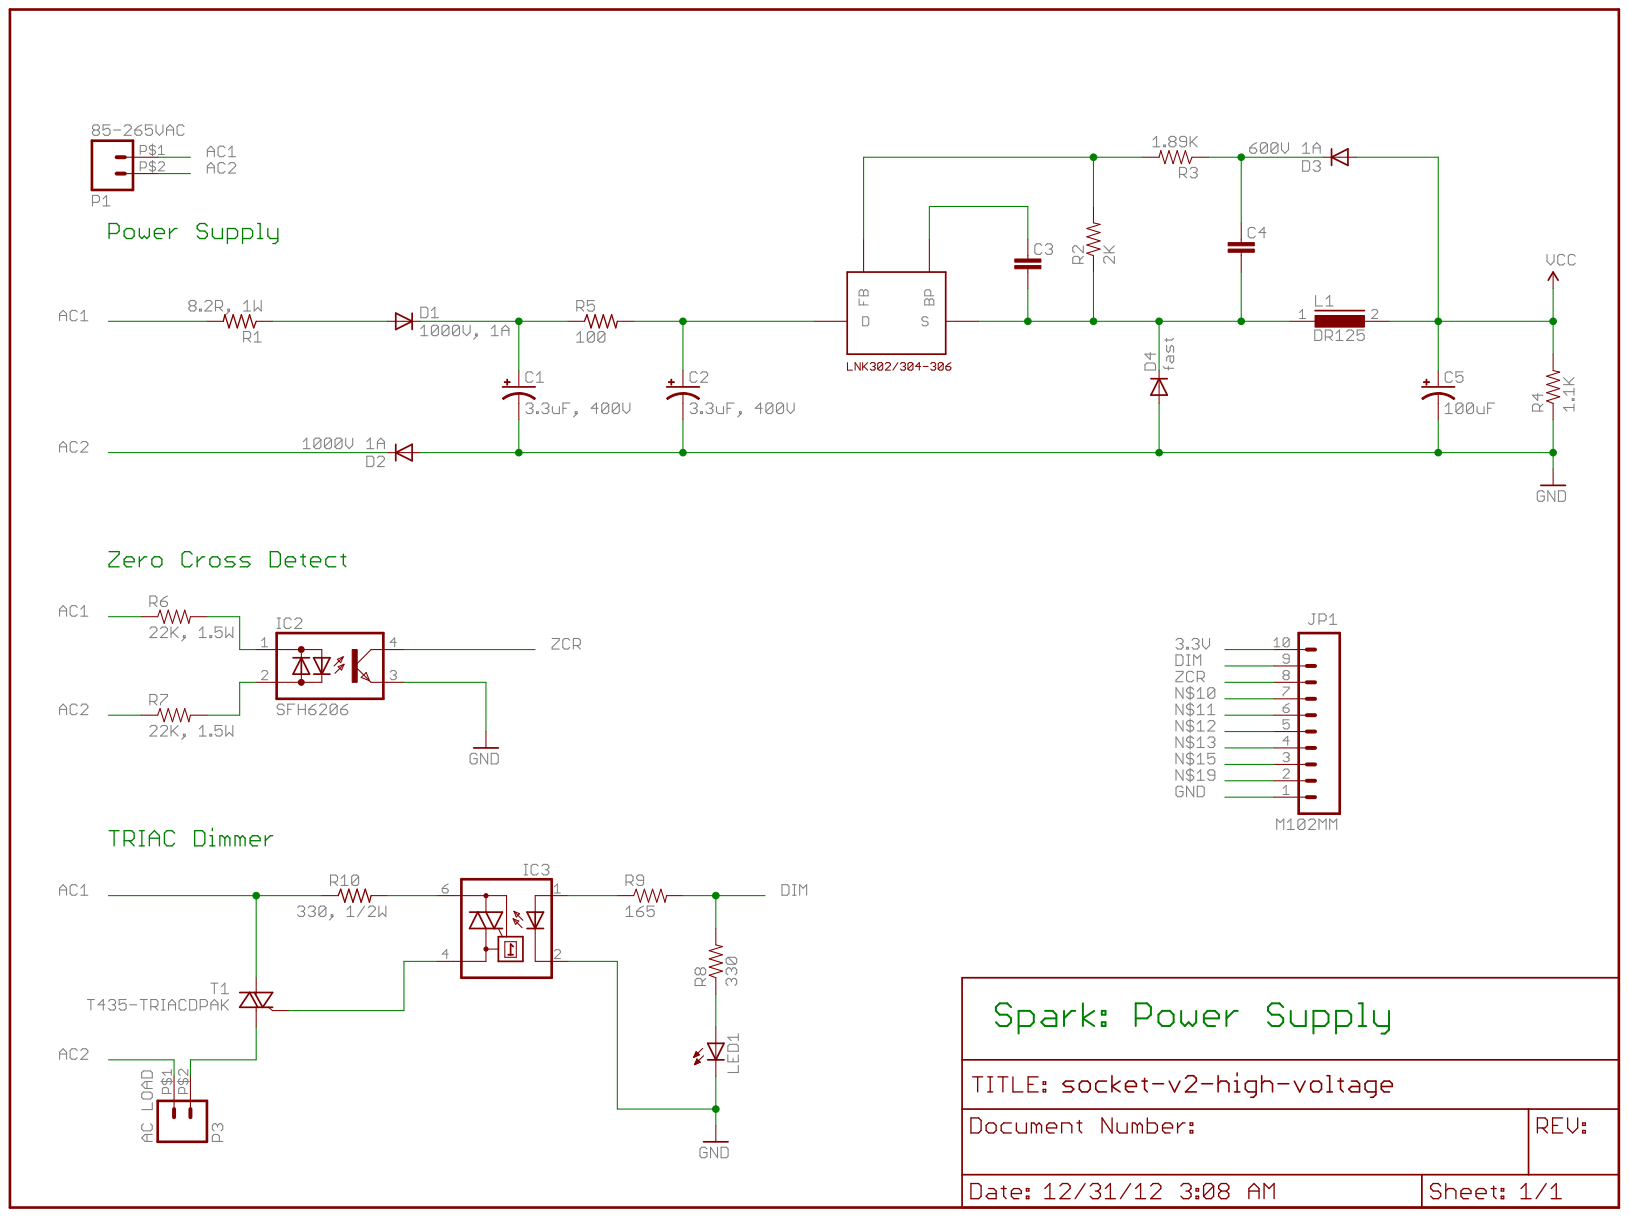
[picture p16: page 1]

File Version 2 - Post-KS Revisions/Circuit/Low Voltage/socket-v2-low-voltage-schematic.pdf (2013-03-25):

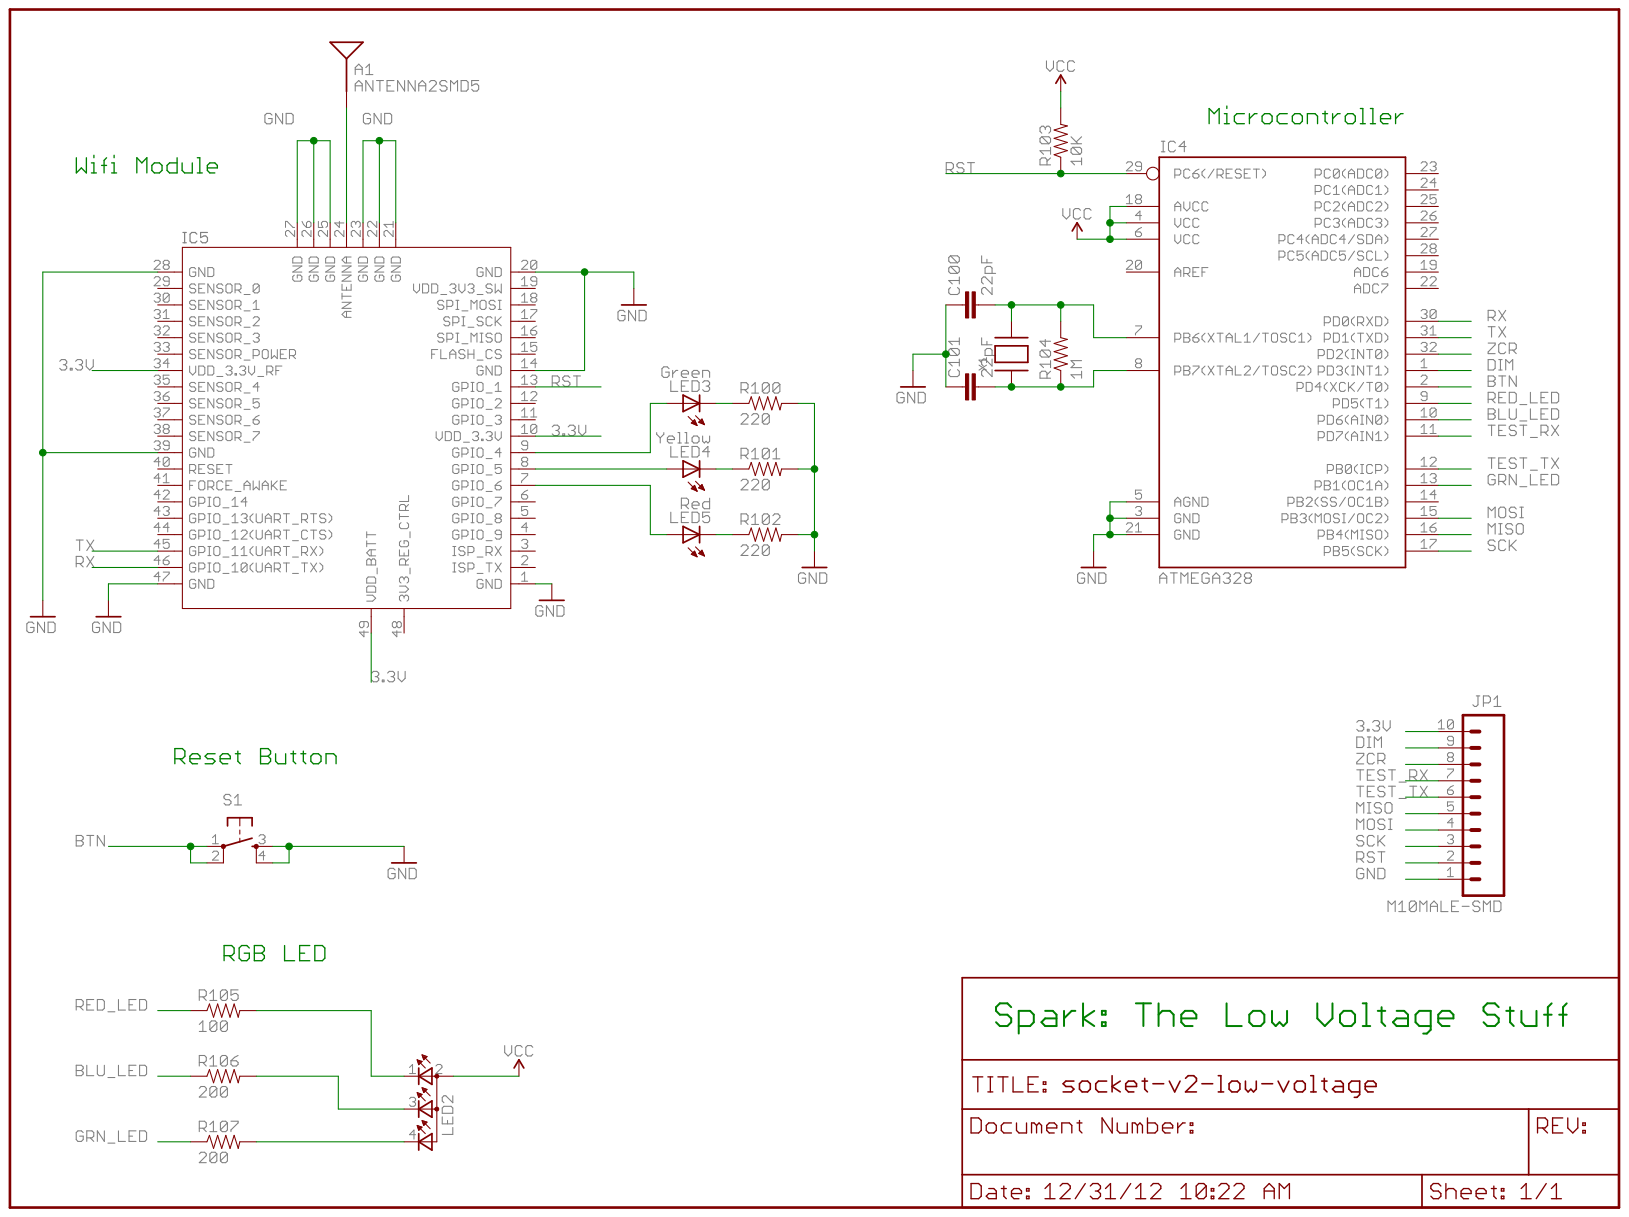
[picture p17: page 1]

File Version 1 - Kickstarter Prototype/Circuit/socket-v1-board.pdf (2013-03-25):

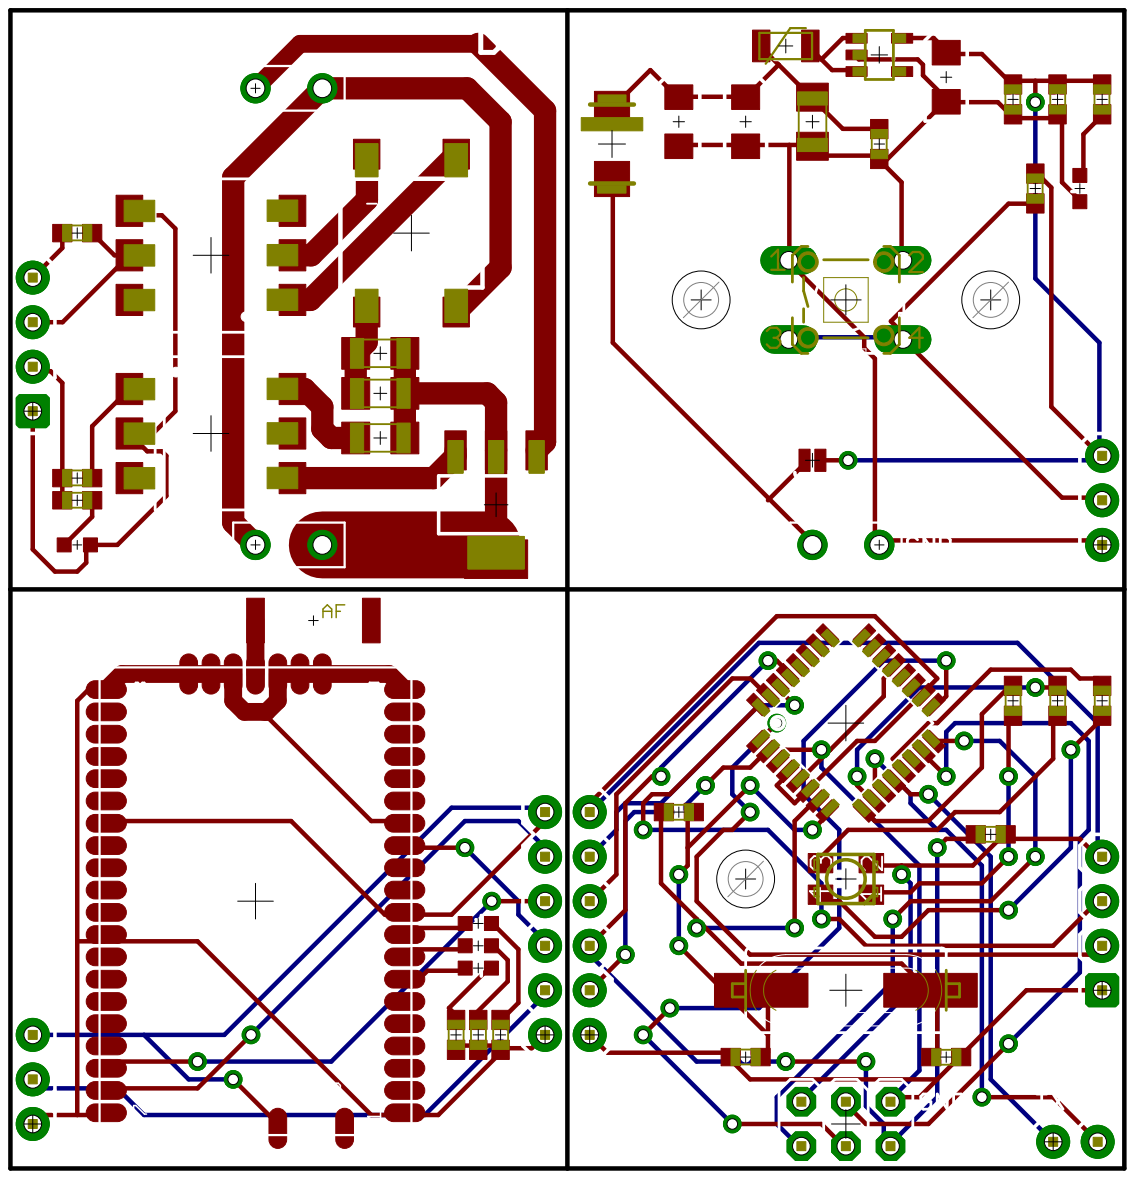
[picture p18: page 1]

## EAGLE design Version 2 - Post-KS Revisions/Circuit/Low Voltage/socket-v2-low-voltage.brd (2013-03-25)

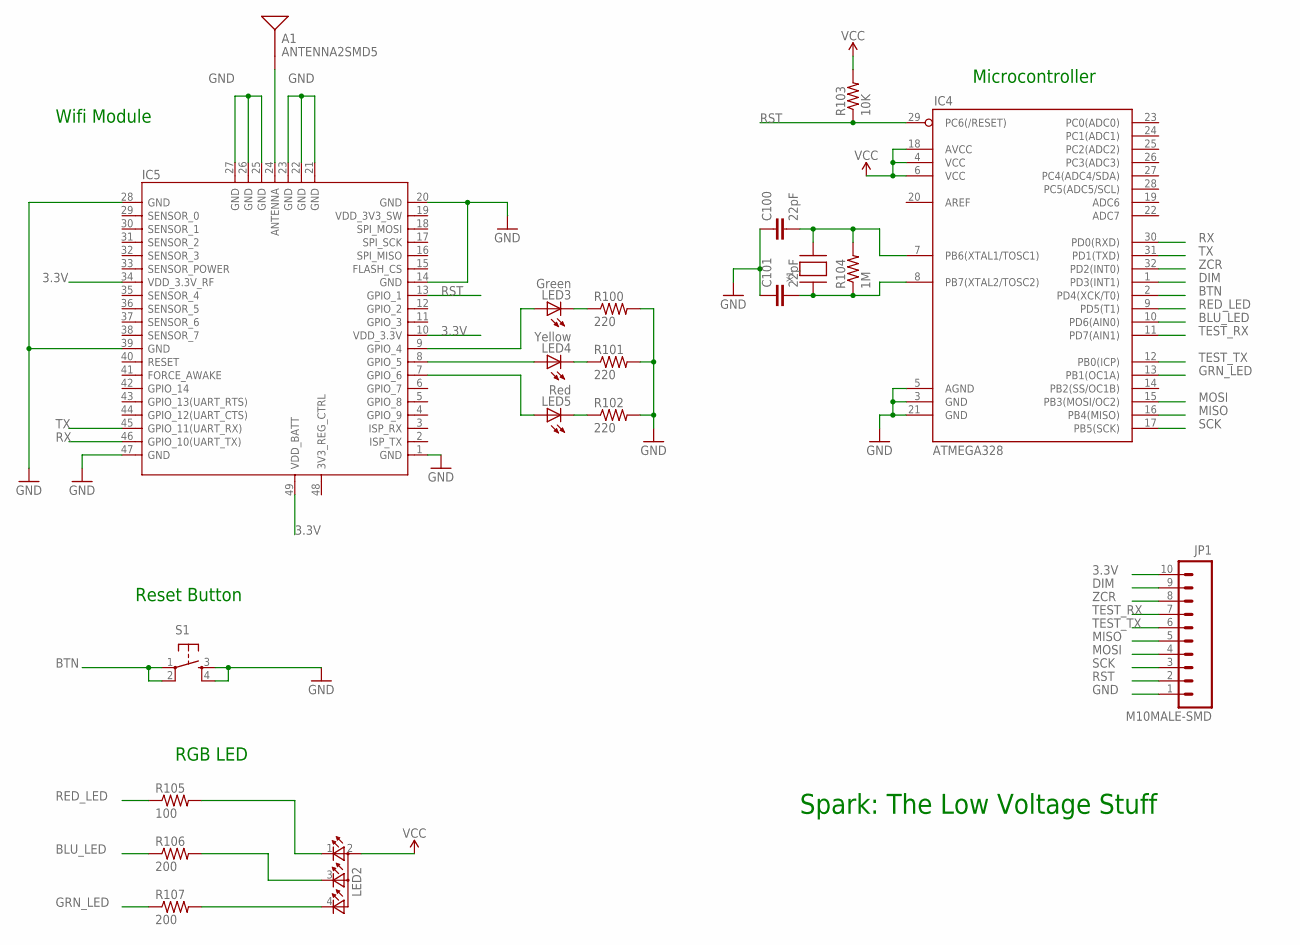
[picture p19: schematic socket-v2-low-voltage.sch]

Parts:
A1: ANTENNA2SMD5; ANTENNA-CHIP5
C100, C101: 22pF; 0603-CAP
IC4: ATMEGA328; TQFP32-08
IC5: WIFI-RN-171; 49P-1.27-26.67X17.78
JP1: M10MALE-SMD; 1X10-2MM-MALE-SMD
LED2: TOPLED-3PLCC; P-LCC-4-3
LED3: Green; LED-0603
LED4: Yellow; LED-0603
LED5: Red; LED-0603
R100, R101, R102: 220; 0603-RES
R103: 10K; 0603-RES
R104: 1M; 0603-RES
R105: 100; 0603-RES
R106, R107: 200; 0603-RES
S1: TAC_SWITCHSMD; TACTILE_SWITCH_SMD
X1: XTALNX5032; NX5032

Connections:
3.3V: IC4.4 (VCC), IC4.6 (VCC), IC4.18 (AVCC), IC5.10 (VDD_3.3V), IC5.34 (VDD_3.3V_RF), IC5.49 (VDD_BATT), JP1.10, LED2.2 (A2), R103.2
BLU_LED: IC4.10 (PD6(AIN0)), R106.1
BTN: IC4.2 (PD4(XCK/T0)), S1.1, S1.2
DIM: IC4.1 (PD3(INT1)), JP1.9
GND: C100.1, C101.1, IC4.3 (GND), IC4.5 (AGND), IC4.21 (GND), IC5.1 (GND), IC5.14 (GND), IC5.20 (GND), IC5.21 (GND), IC5.22 (GND), IC5.23 (GND), IC5.25 (GND), IC5.26 (GND), IC5.27 (GND), IC5.28 (GND), IC5.39 (GND), IC5.47 (GND), JP1.1, R100.2, R101.2, R102.2, S1.3, S1.4
GRN_LED: IC4.13 (PB1(OC1A)), R107.1
MISO: IC4.16 (PB4(MISO)), JP1.5
MOSI: IC4.15 (PB3(MOSI/OC2)), JP1.4
unnamed: LED2.1 (CRED), R105.2
unnamed: LED2.4 (CGREEN), R107.2
unnamed: LED2.3 (CBLUE), R106.2
unnamed: IC5.9 (GPIO_4), LED3.A
unnamed: LED3.C, R100.1
unnamed: LED4.C, R101.1
unnamed: LED5.C, R102.1
unnamed: IC5.8 (GPIO_5), LED4.A
unnamed: IC5.7 (GPIO_6), LED5.A
unnamed: A1.FEED, IC5.24 (ANTENNA)
unnamed: C100.2, IC4.7 (PB6(XTAL1/TOSC1)), R104.2, X1.P$2
RED_LED: IC4.9 (PD5(T1)), R105.1
RST: IC4.29 (PC6(/RESET)), IC5.13 (GPIO_1), JP1.2, R103.1
RX: IC4.30 (PD0(RXD)), IC5.46 (GPIO_10(UART_TX))
SCK: IC4.17 (PB5(SCK)), JP1.3
TEST_RX: IC4.11 (PD7(AIN1)), JP1.7
TEST_TX: IC4.12 (PB0(ICP)), JP1.6
TX: IC4.31 (PD1(TXD)), IC5.45 (GPIO_11(UART_RX))
XTAL1: C101.2, IC4.8 (PB7(XTAL2/TOSC2)), R104.1, X1.P$1
ZCR: IC4.32 (PD2(INT0)), JP1.8

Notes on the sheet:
Wifi Module
Reset Button
RGB LED
Microcontroller
Spark: The Low Voltage Stuff

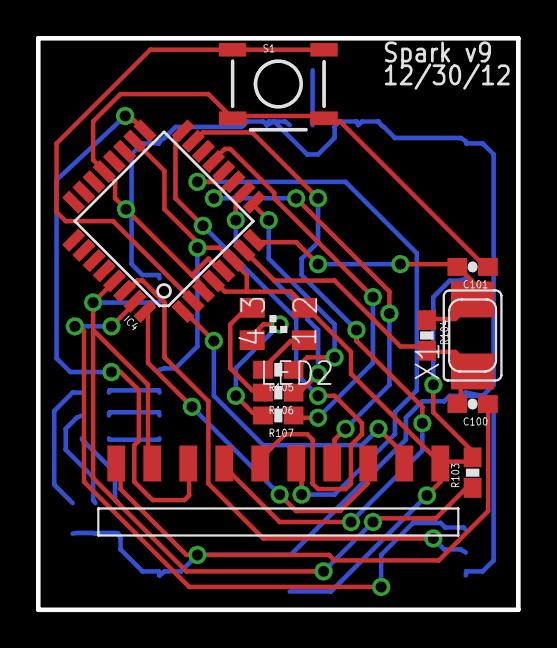
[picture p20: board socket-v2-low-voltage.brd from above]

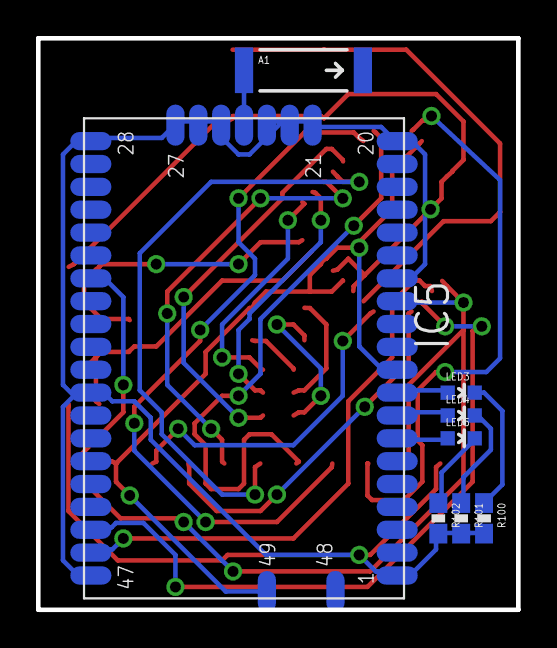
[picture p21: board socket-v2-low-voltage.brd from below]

Board: 2 copper layers, 26.7 x 31.8 mm, 20 parts (8 on the bottom side), 28 nets.

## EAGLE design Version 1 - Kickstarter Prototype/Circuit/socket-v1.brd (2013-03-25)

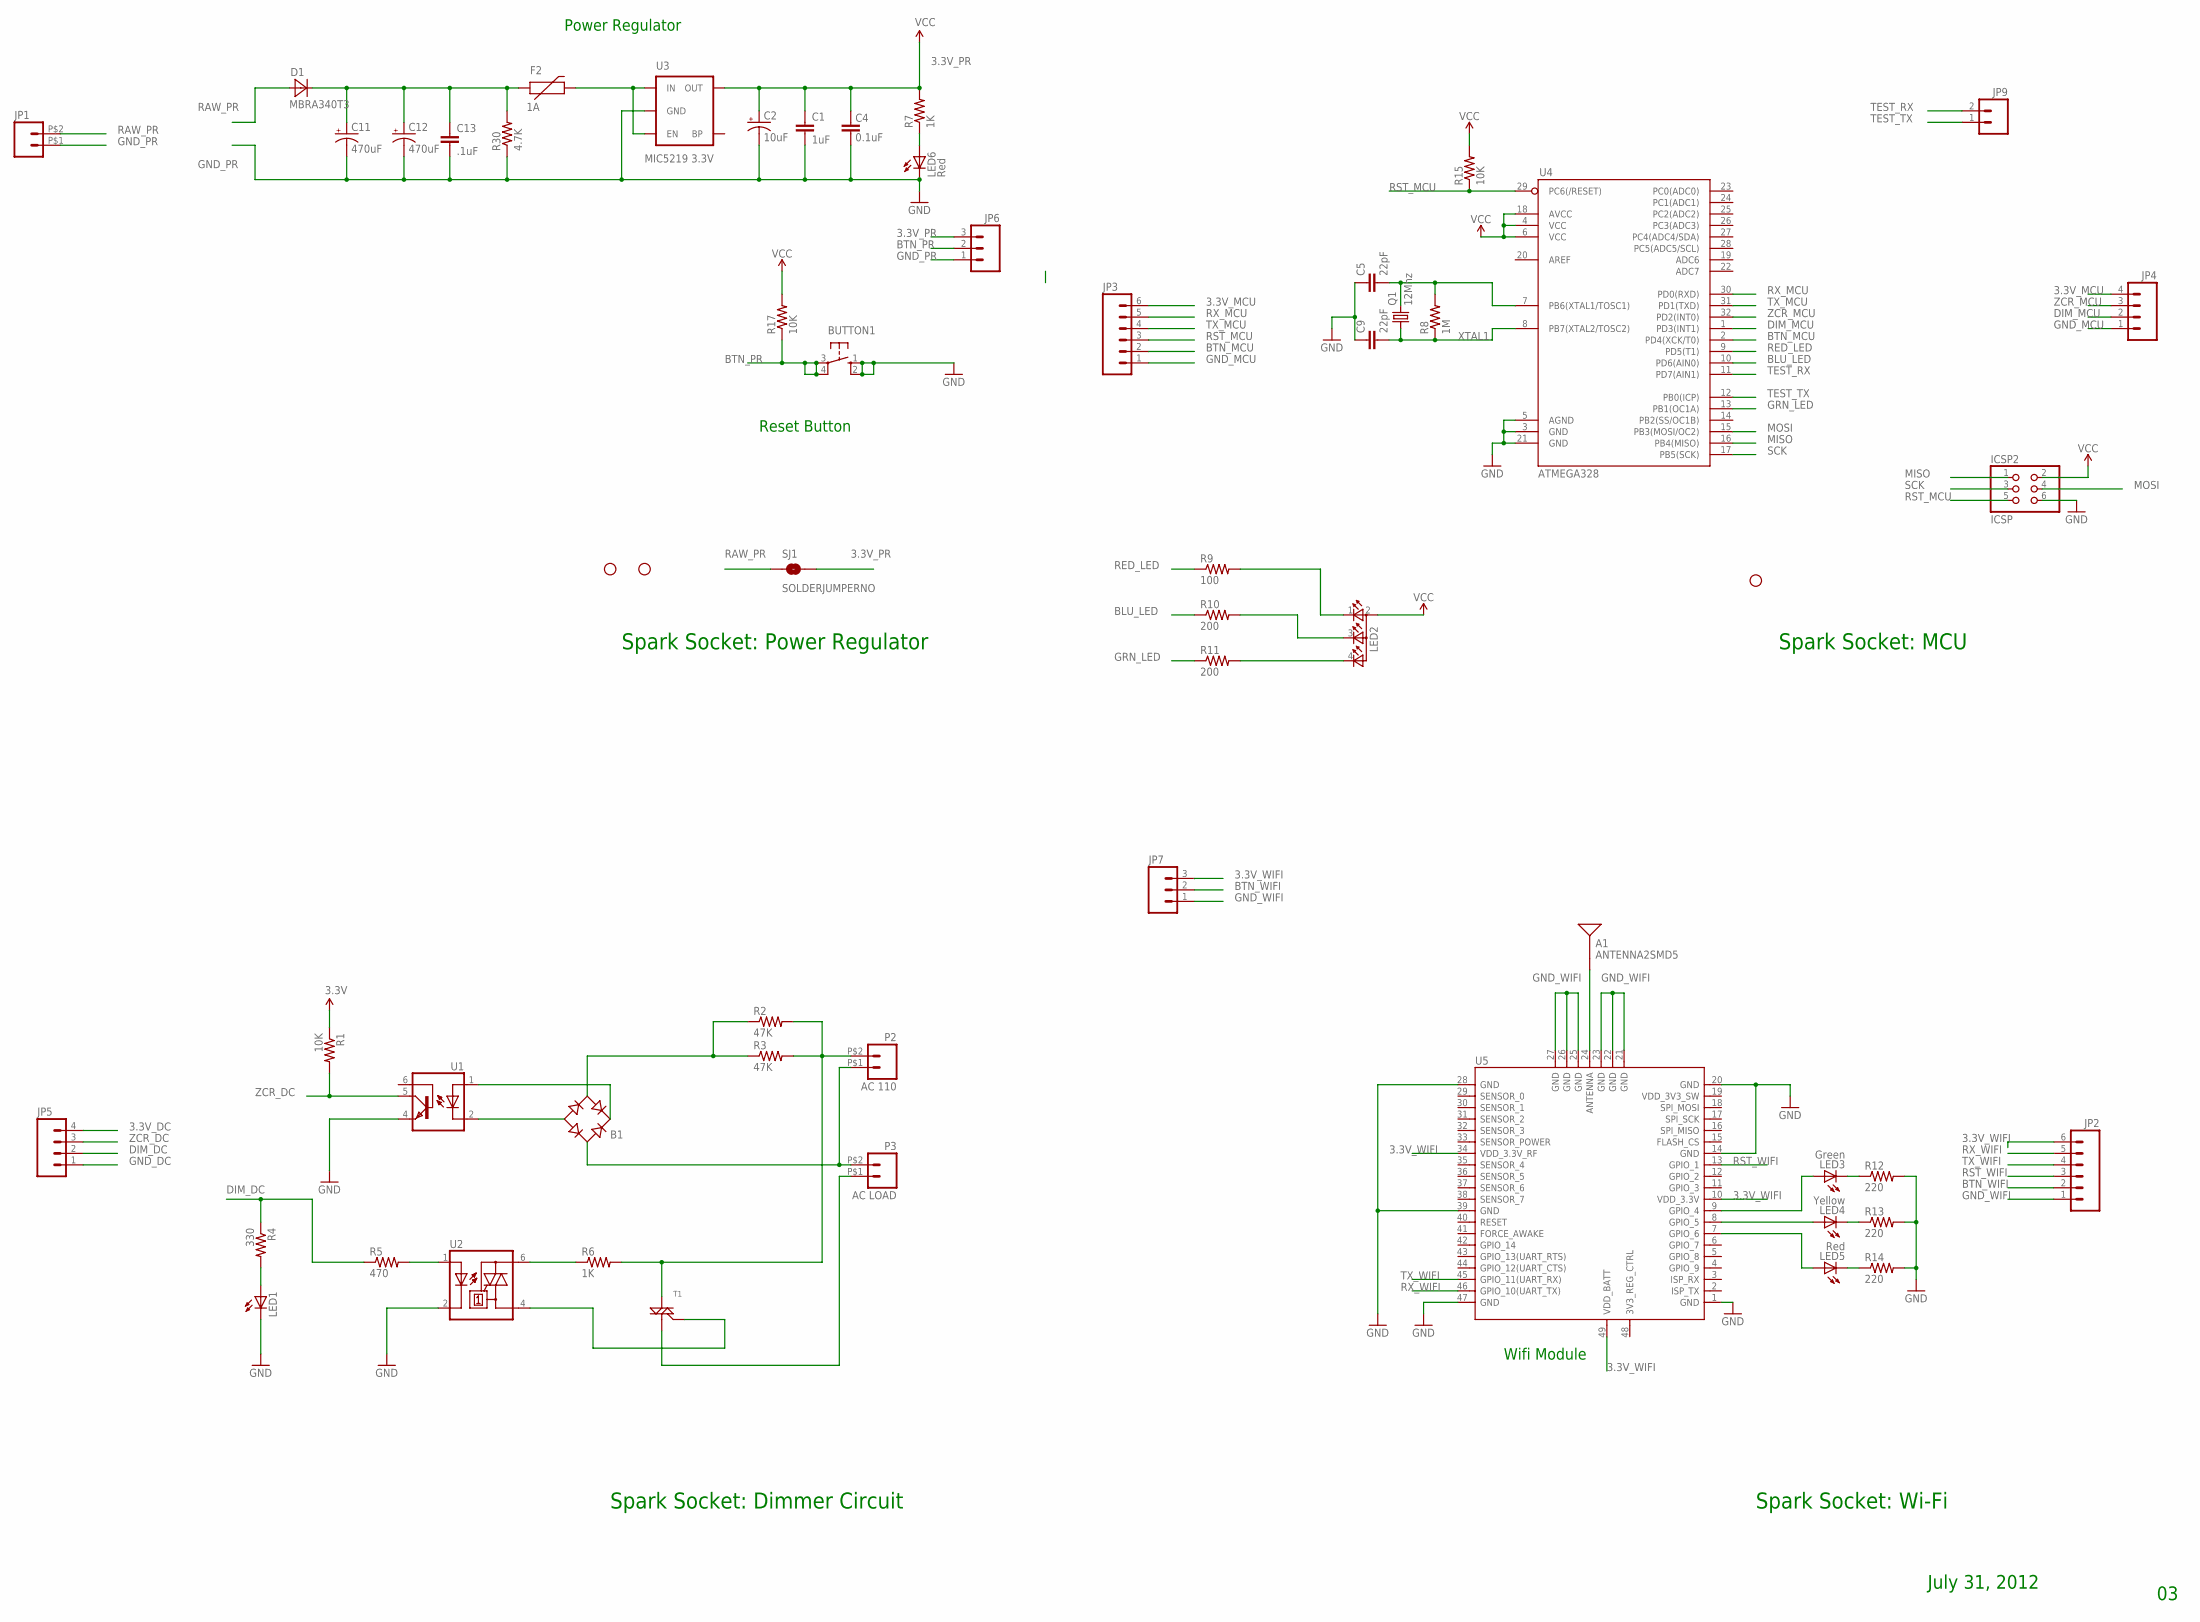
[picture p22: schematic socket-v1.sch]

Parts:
A1: ANTENNA2SMD5; ANTENNA-CHIP5
B1: DF10S; DFS
BUTTON1: 10-XX; B3F-10XX
C1: 1uF; 0603-CAP
C2: 10uF; EIA3216
C4: 0.1uF; 0603-CAP
C5, C9: 22pF; 0603-CAP
C11, C12: 470uF; EIA3216
C13: .1uF; 1206
D1: MBRA340T3; SMA
F2: 1A; PTC-1206
ICSP2: ICSP; 2X03
JP1: M02PTH2; 1X02_BIG
JP2, JP3: M06SIP; 1X06
JP4, JP5: M04PTH; 1X04
JP6, JP7: M03PTH; 1X03
JP8, JP10, JP11: STAND-OFF
JP9: M02PTH; 1X02
LED1: LED0603; LED-0603
LED2: TOPLED-3PLCC; P-LCC-4-3
LED3: Green; LED-0603
LED4: Yellow; LED-0603
LED5, LED6: Red; LED-0603
P2: AC 110; 1X02_BIG
P3: AC LOAD; 1X02_BIG
Q1: 12Mhz; HC49UP
R1, R15, R17: 10K; 0603-RES
R2, R3: 47K; 1206
R4: 330; 0603-RES
R5: 470; 0603-RES
R6: 1K; 1206
R7: 1K; 0603-RES
R8: 1M; 0603-RES
R9: 100; 0603-RES
R10, R11: 200; 0603-RES
R12, R13, R14: 220; 0603-RES
R30: 4.7K; 0603-RES
SJ1: SOLDERJUMPERNO; SJ_2S-NO
T1: TRIACSMD; SOT223
U1: 4N25SM; DIL6-SMD; MPN 4N25SM
U2: MOC3031S; DIL6-SMD; MPN MOC3031SM
U3: MIC5219 3.3V; SOT23-5
U4: ATMEGA328; TQFP32-08
U5: WIFI-RN-171; 49P-1.27-26.67X17.78

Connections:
3.3V_DC: JP5.4, R1.1
3.3V_MCU: ICSP2.2, JP3.6, JP4.4, LED2.2 (A2), R15.2, U4.4 (VCC), U4.6 (VCC), U4.18 (AVCC)
3.3V_PR: C1.1, C2.A (+), C4.2, JP6.3, R7.2, R17.2, SJ1.2, U3.5 (OUT)
3.3V_WIFI: JP2.6, JP7.3, U5.10 (VDD_3.3V), U5.34 (VDD_3.3V_RF), U5.49 (VDD_BATT)
ASDF: C11.A (+), C12.A (+), C13.1, D1.C, F2.1, R30.2
BLU_LED: R10.1, U4.10 (PD6(AIN0))
BTN_MCU: JP3.2, U4.2 (PD4(XCK/T0))
BTN_PR: BUTTON1.3, BUTTON1.4 (P1), JP6.2, R17.1
BTN_WIFI: JP2.2, JP7.2
DIM_DC: JP5.2, R4.1, R5.1
DIM_MCU: JP4.2, U4.1 (PD3(INT1))
GND_DC: JP5.1, LED1.C, U1.4 (EMI), U2.2 (C)
GND_MCU: C5.1, C9.1, ICSP2.6, JP3.1, JP4.1, U4.3 (GND), U4.5 (AGND), U4.21 (GND)
GND_PR: BUTTON1.1 (S), BUTTON1.2 (S1), C1.2, C2.C (-), C4.1, C11.C (-), C12.C (-), C13.2, JP1.P$1 (1), JP6.1, LED6.C, R30.1, U3.2 (GND)
GND_WIFI: JP2.1, JP7.1, R12.2, R13.2, R14.2, U5.1 (GND), U5.14 (GND), U5.20 (GND), U5.21 (GND), U5.22 (GND), U5.23 (GND), U5.25 (GND), U5.26 (GND), U5.27 (GND), U5.28 (GND), U5.39 (GND), U5.47 (GND)
GRN_LED: R11.1, U4.13 (PB1(OC1A))
MISO: ICSP2.1, U4.16 (PB4(MISO))
MOSI: ICSP2.4, U4.15 (PB3(MOSI/OC2))
unnamed: LED2.1 (CRED), R9.2
unnamed: LED6.A, R7.1
unnamed: F2.2, U3.1 (IN), U3.3 (EN)
unnamed: B1.-, U1.2 (C)
unnamed: B1.+, U1.1 (A)
unnamed: B1.AC2, R2.1, R3.1
unnamed: P2.P$2 (2), R2.2, R3.2, R6.2, T1.2 (M2)
unnamed: LED2.4 (CGREEN), R11.2
unnamed: R6.1, U2.6 (A2)
unnamed: T1.3 (G), U2.4 (A1)
unnamed: P3.P$1 (1), T1.1 (M1)
unnamed: B1.AC1, P2.P$1 (1), P3.P$2 (2)
unnamed: LED1.A, R4.2
unnamed: LED2.3 (CBLUE), R10.2
unnamed: R5.2, U2.1 (A)
unnamed: LED3.A, U5.9 (GPIO_4)
unnamed: LED3.C, R12.1
unnamed: LED4.C, R13.1
unnamed: LED5.C, R14.1
unnamed: LED4.A, U5.8 (GPIO_5)
unnamed: LED5.A, U5.7 (GPIO_6)
unnamed: A1.FEED, U5.24 (ANTENNA)
unnamed: C5.2, Q1.2, R8.2, U4.7 (PB6(XTAL1/TOSC1))
RAW_PR: D1.A, JP1.P$2 (2), SJ1.1
RED_LED: R9.1, U4.9 (PD5(T1))
RST_MCU: ICSP2.5, JP3.3, R15.1, U4.29 (PC6(/RESET))
RST_WIFI: JP2.3, U5.13 (GPIO_1)
RX_MCU: JP3.5, U4.30 (PD0(RXD))
RX_WIFI: JP2.5, U5.46 (GPIO_10(UART_TX))
SCK: ICSP2.3, U4.17 (PB5(SCK))
TEST_RX: JP9.2, U4.11 (PD7(AIN1))
TEST_TX: JP9.1, U4.12 (PB0(ICP))
TX_MCU: JP3.4, U4.31 (PD1(TXD))
TX_WIFI: JP2.4, U5.45 (GPIO_11(UART_RX))
XTAL1: C9.2, Q1.1, R8.1, U4.8 (PB7(XTAL2/TOSC2))
ZCR_DC: JP5.3, R1.2, U1.5 (COL)
ZCR_MCU: JP4.3, U4.32 (PD2(INT0))

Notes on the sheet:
Spark Socket: Wi-Fi
July 31, 2012
Spark Socket: MCU
Spark Socket: Power Regulator
Spark Socket: Dimmer Circuit
Power Regulator
Wifi Module
Reset Button

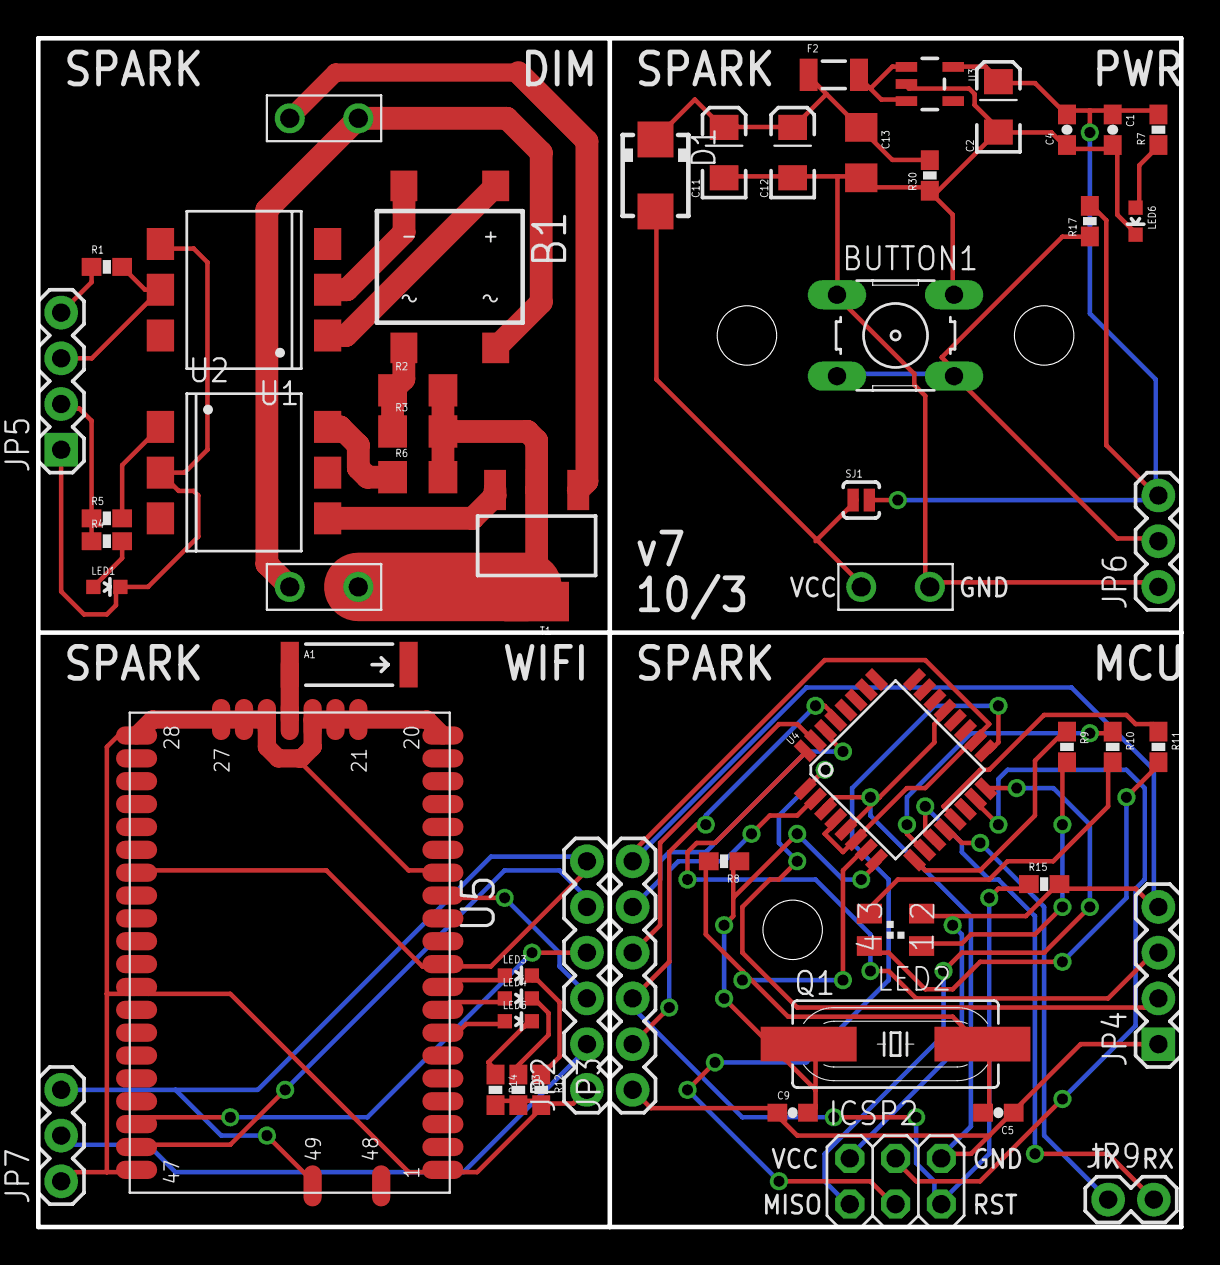
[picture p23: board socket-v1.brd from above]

Board: 2 copper layers, 63.5 x 66.0 mm, 58 parts (0 on the bottom side), 55 nets.

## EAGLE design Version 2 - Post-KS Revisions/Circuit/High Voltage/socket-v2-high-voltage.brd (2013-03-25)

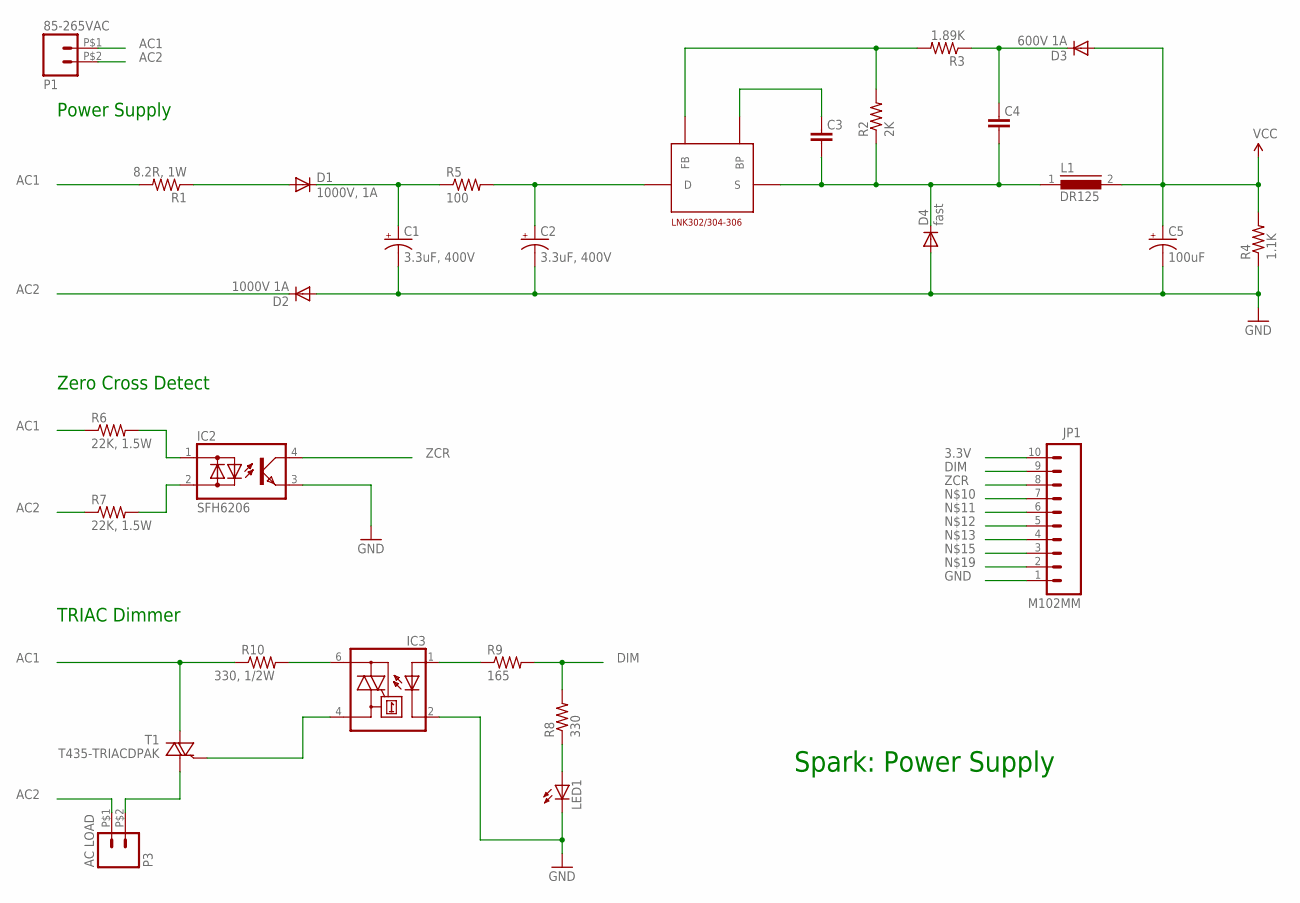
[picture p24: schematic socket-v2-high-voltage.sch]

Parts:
C1, C2: 3.3uF, 400V; E3,5-8
C3: 0.1uF; 0603-CAP
C4: 10uF, 50V; 0805
C5: 100uF; EIA3528
D1: 1000V, 1A; SMA-DIODE
D2: 1000V 1A; SMA-DIODE
D3: 600V 1A; SMA-DIODE
D4: fast; SMA-DIODE
IC1: LNK302/304-306; SMD-8B
IC2: SFH6206; DIL4-SMD
IC3: MOC3031S; DIL6-SMD; MPN MOC3031SM
JP1: M102MM; 1X10-2MM
L1: DR125
LED1: LED0603; LED-0603
P1: 85-265VAC; 1X02_BIG
P3: AC LOAD; 1X02_BIG
R1: 8.2R, 1W; 0207/10
R2: 2K; 0805
R3: 1.89K; 0805
R4: 1.1K; 0603-RES
R5: 100; 0204/7
R6, R7: 22K, 1.5W; R2512
R8: 330; 0805
R9: 165; 0805
R10: 330, 1/2W; R1210
T1: T435-TRIACDPAK; TO252

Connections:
3.3V: C5.A (+), D3.A, JP1.10, L1.2, R4.2
$N$100: C3.1, C4.1, D4.C, IC1.S1 (S), L1.1, R2.1
$N$101: C2.+, IC1.D, R5.2
AC1: P1.P$1 (1), R1.2, R6.1, R10.1, T1.2 (A2)
AC2: D2.C, P1.P$2 (2), P3.P$1 (1), R7.1
DIM: JP1.9, R8.2, R9.2
GND: C1.-, C2.-, C5.C (-), D2.A, D4.A, IC2.3 (E), IC3.2 (C), JP1.1, LED1.C, R4.1
unnamed: C4.2, D3.C, R3.1
unnamed: C3.2, IC1.BP
unnamed: IC3.1 (A), R9.1
unnamed: IC3.6 (A2), R10.2
unnamed: IC3.4 (A1), T1.3 (G)
unnamed: P3.P$2 (2), T1.1 (A1)
unnamed: IC2.1 (AC1), R6.2
unnamed: LED1.A, R8.1
unnamed: C1.+, D1.C, R5.1
unnamed: IC1.FB, R2.2, R3.2
unnamed: IC2.2 (AC2), R7.2
RAW_PR: D1.A, R1.1
ZCR: IC2.4 (C), JP1.8

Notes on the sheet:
Power Supply
Spark: Power Supply
Zero Cross Detect
TRIAC Dimmer

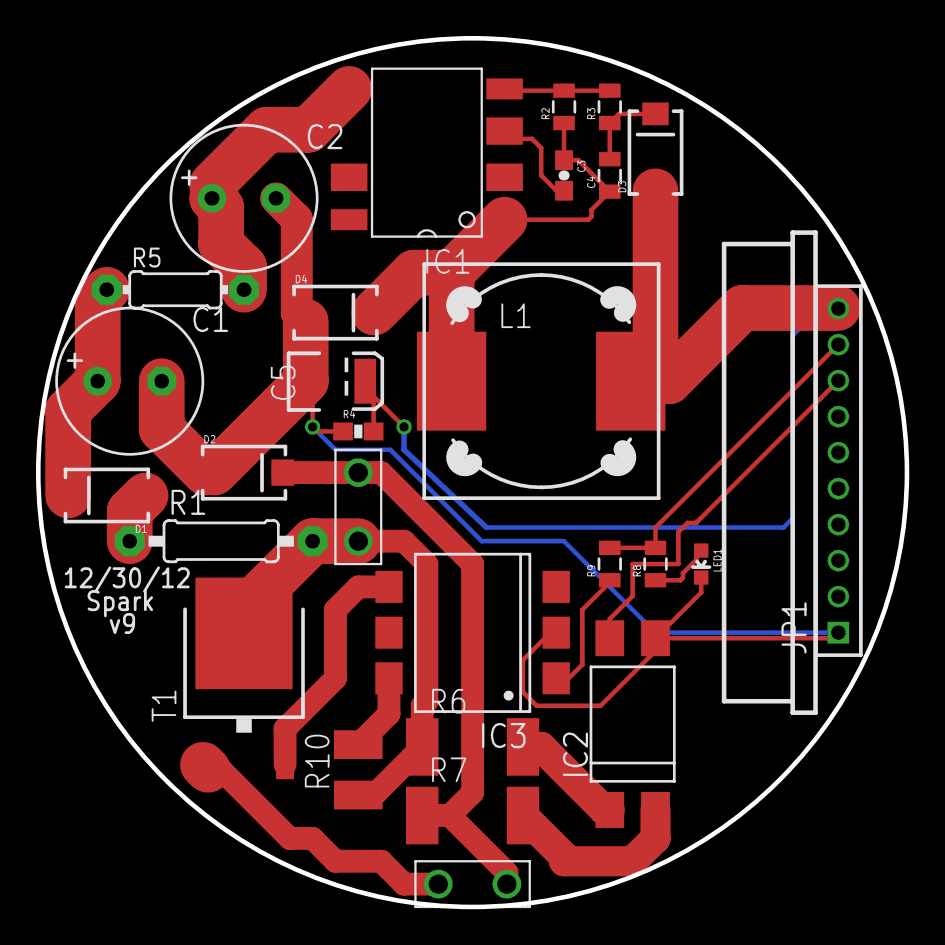
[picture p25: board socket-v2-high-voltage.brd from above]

Board: 2 copper layers, 48.3 x 48.3 mm, 28 parts (0 on the bottom side), 20 nets.

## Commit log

2013-03-25 Added files and updated README
    [20121022_Spark_BOM v3.xlsx, 20121029 Spark_worksheet v5.xlsx, Housing Assembly.SLDASM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]
2013-03-25 Cleaned up filenames and added latest files
    [socket-v1-bom.xlsx, socket-v1-inner-shell.STEP, socket-v1-outer-shell.STEP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]
2013-03-25 Removed deleted files
    [20121022_Spark_BOM v3.xlsx, 20121029 Spark_worksheet v5.xlsx, Housing Assembly.SLDASM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]

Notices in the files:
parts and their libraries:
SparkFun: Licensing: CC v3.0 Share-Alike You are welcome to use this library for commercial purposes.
